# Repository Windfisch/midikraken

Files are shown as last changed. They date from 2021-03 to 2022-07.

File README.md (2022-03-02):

Midikraken
==========



binary_size (https://seriesci.com/Windfisch/midikraken/series/binary_size)

An open-source, open-hardware MIDI-USB-interface supporting up to 16
(and maybe beyond?) MIDI ports. The hardware is based on a STM32F103
*"blue pill"* board which can be cheaply sourced from your favourite chinese
seller ([note about quality differences](https://github.com/Windfisch/analog-synth/blob/master/bluepill.md)),
plus other garden variety components such as HC2630 opto couplers (that's just
two 6N137 in one package), shift registers, some LEDs and resistors.

Apart from being a MIDI-USB-interface, Midikraken is a feature-packed MIDI
router supporting separate clock and note event routing, clock division.
Future features may include split-keyboard routing, clock generation or even a
hardware arpeggiator.

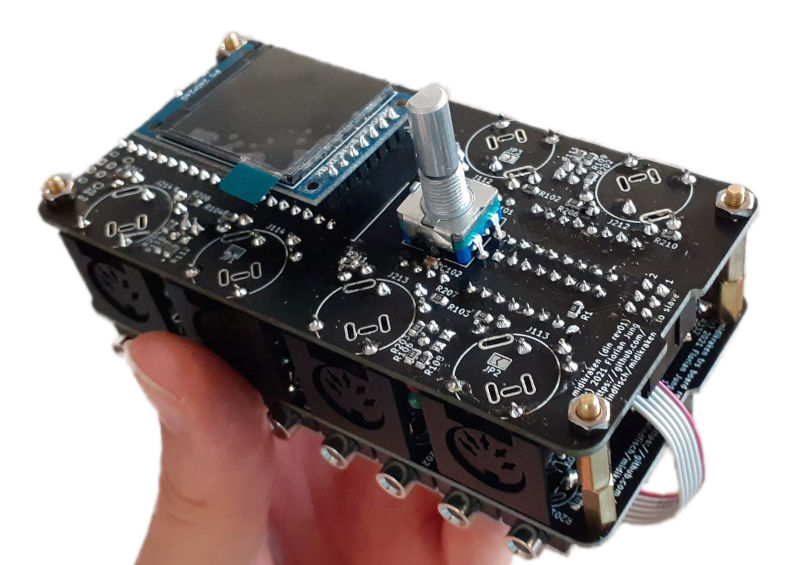
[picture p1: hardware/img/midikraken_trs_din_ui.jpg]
Example of a Midikraken configuration


Below you will find a technical overview. [A user manual is available here](documentation/README.md).

Releases
--------

Find the latest firmware upgrade packages [on the releases page](https://github.com/Windfisch/midikraken/releases).
You only need an USB cable, instructions for Linux and Windows are included.

The schematics and board layout files are [on a separate page](https://github.com/Windfisch/midikraken-hardware/releases).
Hardware and firmware are versioned separately, their numbers do not match.

Hardware
--------

Midikraken consists of two different PCBs that can be stacked (almost)
arbitrarily: [The DIN board](hardware/din5_pcb) has four traditional MIDI
in/out port pairs, and can house the master microcontroller.

[The TRS board](hardware/trs_pcb) gives you eight TRS MIDI pairs that support
both TRS-A and TRS-B. (Inputs are automatic, outputs need to be configured
in software). It can not house the microcontroller and thus cannot be used
without a DIN board.

The boards can be chained using their master/slave connectors and are
stackable using M3 screws / spacers. Currently, the firmware must be
adapted and recompiled according to the stack configuration. Currently,
a maximum of 16 port pairs is supported.

For information on the hardware, the revision history and errata, see [the hardware documentation](hardware/README.md).
A [build guide](documentation/build_guide/README.md) for rev01 and rev02 is available.

Firmware
--------

The firmware is written in Rust and is released under the GPLv3 license.

Since the STM32F103 only offers 3 hardware UARTs, we need to emulate the UART
protocol in software. For this, a timer interrupt oversamples the UART input pins
with thrice the baudrate in order to always read a stable bit at a non-edge.
(Guaranteed 1/3 * bit time distance from any edge, so the signal should be quite
stable until then.)

[Benchmarks show](firmware/benchmark/README.md) that this can be done fast
enough for up to 16 software UARTs (and likely even more), while leaving
plenty of cpu cycles (25% for 16 UARTs) free for other work.

Further information about the firmware itself can be found
[in the firmware documentation](firmware/README.md).

License
-------

The software in the [firmware](firmware) directory can be redistributed
and/or modified under the terms of the
[GNU General Public License Version 3](gpl3.txt). Note this does not apply
to the [bootloader](firmware/sboot/sboot_stm32) which is under its own
license.

The hardware designs in the [hardware](hardware) directory, excluding
[hardware/lib/3d](hardware/lib/3d) to which own conditions apply, can be
licensed under the terms of the [CERN OHL Version 2 license](cern_ohl_s_v2.txt).
This specifically includes (but is not limited to) schematics, PCB designs and
gerber files.

Contributing
------------

I am happy about contributions, just open a pull request!

**Note:** Even though Midikraken is licensed under GPLv3 and OHL-S-v2 (the exact
versions), any contributions / pull requests must be licensed under the
"GPLv3 *or any later version*" or "OHL-S-v2 *or any later version*", respectively.
This is because on the one hand, I want to be able to update the project to new
versions of these licenses, but on the other hand, I don't like licensing my work
under a license (e.g. the hypothetical GPLv4) that I haven't even read yet. If such
a license is released, I will likely adopt it after revising it.

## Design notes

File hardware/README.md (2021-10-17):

Midikraken hardware
===================

This page describes the hardware itself. A [build manual is available here](../documentation/build_guide/README.md).

Midikraken boards are meant to be **stacked** using M3 spacers and screws.
In such a setup, one "master" exists that holds the microcontroller with
the USB port, and zero or multiple "slaves" are daisy-chained with their
upstream ("from master") or downstream ("to slave") ports.

Photo of Midikraken

The photo shows an (almost) fully equipped Midikraken including:

- 1 DIN connector board (the large MIDI connectors).
- 1 TRS connector board (MIDI via headphone jacks).
- The main microcontroller
- The UI consisting of a display and a rotary encoder.

Midikraken boards can be stacked almost arbitrarily; the only limit is
(currently) a maximum of 16 MIDI in/out port pairs.

Two board types are available:
- The DIN board with four DIN MIDI inputs and four outputs
- and the TRS board with eight TRS inputs and eight outputs.

DIN boards may or may not house the main microcontroller, so every stack needs
one. Note that the DIN board can be used to house only the microcontroller, if
desired. No actual MIDI ports need to be equipped, making a TRS-only stack
possible.

The TRS board supports both TRS-MIDI-A and -B (where roles of tip and ring
are swapped).

Note that while it would be possible to design boards with
only inputs or only outputs, the current boards do *not* support switching
an input port to output mode or vice versa. If desired, however, inputs
can be left unmounted; in this case, the appropriate LEDs and opto-couplers
can be left out, too.

Board variants
--------------

Both boards can be built in different variants. For the DIN board, the options
include:

- It can either house the **microcontroller** *(A1)* or act as a **slave** *(A2).
- It can hold **angled MIDI connectors** (*B1*, the default), or **not have any connectors** *(B2)*.
  (This is useful when used as user interface board only). *(Additionally, there
  is a somewhat hacky way to mount upward-facing MIDI connectors to it for use
  in Eurorack setups, but that's dirty and untested.)*
- If the board is configured as a master, it can or can not have a **user
  interface** *(C)* consisting of a display and a rotary knob with a push button.
- If the board holds a microcontroller, it can support chaining more boards to it *(D1)*,
  or save some components at the cost of losing the chaining ability *(D2)*. (*not
  recommended*).
- In this case, MIDI can be driven with 5V *(E1)* or with 3.3V *(E2, saves another chip, 
  not recommended)*.
- As a the buffer U1, a 74HCT245 *(F1)* or 74HCT541 *(F2)* can be used.

For the TRS board, two options are available:
- Either 8 in/out port pairs are mounted *(X1)*
- or only one side is equipped with only 4 in/out pairs *(X2)*
- **Angled TRS jacks** (PJ-324) *(Y1)* or **upright** TRS jacks *(Y2)* can be used.

The following components need or need not be mounted on the PCB:
- *(A1)*: mount A1, J1, U1; leave J3 unmounted.
- *(A2)*: mount J3, leave A1, J1, U1 unmounted.
- *(B1)*: mount J10x and J20x, U101, U102, U2, U3 and Dxxx.
- *(B2)*: do not mount the components from *(B1)*, instead run a copper wire across *TODO*.
- *(C)*: mount or do not mount J8 and SW1.
- *(D2)*: Close JP1-4, and close JP5-8 according to your selection in *(E)*.
- *(E2)*: Do not equip U1.
- *(F)*: Configure JP9 accordingly.
- *(X2)*: Close JP102 and do not mount Jx05-Jx08, and all LEDs and resistors on this side.
 Also do not mount U205-U208.
- *(Y)*: Solder in what is needed, the PCB can hold both.

**Note:** While this sounds complicated, in the recommended default configuration which is reflected
by the BOM and schematics, only JP9 needs to be closed to select the IC type used in U1. All other
solder bridges are left open and no deviations from the schematic need to be made, except for *(A)*.

Currently, two different hardware revisions exist. They are described here from most recent to
oldest.

Revision 01
-----------

### Bill of material

[din5_pcb/bom.html](https://htmlpreview.github.io/?https://github.com/Windfisch/midikraken/blob/master/hardware/din5_pcb/bom.html),
[interactive BOM](https://htmlpreview.github.io/?https://github.com/Windfisch/midikraken/blob/master/hardware/din5_pcb/ibom.html)

[trs_pcb/bom.html](https://htmlpreview.github.io/?https://github.com/Windfisch/midikraken/blob/master/hardware/trs_pcb/bom.html),
[interactive BOM](https://htmlpreview.github.io/?https://github.com/Windfisch/midikraken/blob/master/hardware/trs_pcb/ibom.html)

### Errata

During powerup, the MIDI ports send garbage bits. To fix this,
you need to disconnect the 74HC595s' *output enable* pins from GND
using a sharp knife (and some wire to reconnect all GNDs that should stay
connected), and connecting them like this instead:

```
+5V --- Capacitor 10µF --- OE pin --- Resistor 10k --- GND
```

This delays the output enable enough such that the shift registers can
be filled with proper data after the microcontroller has booted up.

The exact fixing procedure is described in [this document](../documentation/rev01_fix/README.md).

### Eurorack compatibility

Please note that Midikraken was designed as a standalone adapter box. However,
where possible, efforts were made to make Midikraken as Eurorack compatible as
possible:

- The PCBs are 110mm in height, fitting tightly into any Eurorack setup.
- The boards are prepared for upright connectors. This is sort of hacky, but it
  might work. The TRS board can hold PJ392 sockets that are usually meant to
  have wires soldered to their legs. The DIN board can hold DIN sockets similar
  to the NYS325, with a hack: The outermost two solder tail must be removed, and
  the remaining three must be bent so that they fit into the PCB.
- Alternatively, any socket can be used and wires can be soldered to the PCB.

Enclosure
---------

Midikraken can either be built half-open as shown in the photo above, or can be
protected from dust and metallic parts with a 3d-printed enclosure.  The
enclosures reflect Midikraken's modular nature and itself can be stacked onto
each other. Currently, three enclosure modules exist:

- The [**display shell**](cad/display_shell.FCStd) which is put on top of the DIN5
  PCB and holds the display.  It terminates the Midikraken stack to the upper
  side.
- The [**DIN5 shell**](cad/din5_shell.FCStd) which is put on the opposite side of
  the DIN5 PCB and covers the MIDI ports, leaving cutouts for the LEDs and the
  USB port.
- The [**TRS shell**](cad/trs_back_shell.FCStd) which covers the ports of the TRS
  PCB and terminates the Midikraken stack.
- Additionally, the [**display top plate**](frontplate) and [**back plate**](backplate)
  are alternatives to the display shell and should be used in the half-open,
  caseless configuration to support the display and protect the circuitry.

The enclosure light guides that cover the LED holes and make it easier to see
the LEDs from an angle. These guides are to be printed with transparent material
and are snapped in from the inside.
(DIN5 needs 4 of [these](cad/din5_lightguide.FCStd) and TRS needs 8 of [these](cad/trs_lightguide.FCStd))

Yet to be done:

- A **terminating DIN5 shell** with a bottom plate for builds without a TRS shell.
- A **non-terminating TRS shell** for builds that use more than one TRS board.
  Note that currently, the firmware only supports a maximum of 16 MIDI ports, which
  rules out a two-TRS-board-solution for now.

Ghettokraken on perfboard
-------------------------

Schematics for the first prototype board were created with KiCAD and are
located in [perfboard](perfboard).

A 3D-printed enclosure (which needs some adjustments to fit well) was
designed in FreeCAD and resides in [perfboard/cad/](perfboard/cad/).
The enclose provides the DIN ports with additional stability which the
usual perfboards lack.

**Note**: You need to use the firmware from 7072a0c6eb or earlier due
different pin assignment; or you reassign the pins.

This roughly resembles the *(D2, E2)* configuration

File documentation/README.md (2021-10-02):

Midikraken user manual
======================

This user manual is targeted to the tech-savvy end user who wants to assemble
Midikraken and get started as quick as possible. Technical details are not discussed here.

If you have received a Midikraken DIY kit, follow [the build guide](build_guide/README.md)
and assemble the Midikraken.

To update the firmware, see [the firmware upgrade manual](firmware_upgrade/README.md).

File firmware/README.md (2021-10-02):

Firmware
--------

The firmware is written in Rust. It can be used either bare metal or with a
bootloader.

### Flashing without a bootloader

  - Connect RX/TX of your uart/usb-adapter to PA9/PA8.
  - Put the STM32 into download mode by setting BOOT0 high and resetting.
  - `cd firmware`
  - `make flash.bare.release` (assuming that `ttyUSB0` is your uart adapter)

### Flashing and using a bootloader

#### Preparing the bootloader

Building with the `--features=bootloader` flag enabled will relocate the
program entry point to `FLASH + 0x2000`, allowing to use a bootloader.

Follow [these steps](sboot/README.md) in order to build and
initially flash the bootloader. You only need to perform this once.

#### Flashing the firmware

Bootloader mode can be entered by sending the `sboot/bootloader.syx` sysex to
the zeroth output of the midikraken (e.g. using `amidi -p hw:1,0,0 -s bootloader.syx`).

If that does not work (e.g. because the firmware is not present or corrupt), pull
PB12 low and reset.

  - Connect the Midikraken to USB
  - (in case of a defective firmware, pull PB12 low and reset)
  - `cd firmware`
  - `make flash.dfu.release` (will send the reset sysex automatically)

### Debugging

printf-debugging can be seen on PA9/PA10 with 38400 baud. In the default
configuration, you should see only

```
========================================================
midikraken @ 6b3d42c5bf369a8da5d348a39342b91c2a3f7e80
      built on 2021-04-09T18:50:50.306707469+00:00
========================================================
```

You can enable more debug information with the `debugprint` flag.

Note that this degrades performance close to being unusable.

### Benchmarking

The software UART timer interrupt fires 93750x per second. This leaves
only 768 cpu cycles per call to the ISR.

To measure the performance of the software UART in the worst-case scenario
(all receivers are receiving their last bit and thus are finishing, and all
senders fetch their next byte and start transmitting it), enable the
`benchmark feature flag`. Note that this will send and receive garbage data.

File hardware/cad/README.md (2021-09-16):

# Enclosures

Midikraken can optionally be put in an enclosure to protect it from dust and metallic parts that
could get inside.  Alternatively, it can be left half-open.

## Modular closed solution

For the closed solution, 3D-print the `display_shell`, `trs_back_shell` and `din5_shell`. You need
4x 22mm M3 spacers, 4x M3 screws and 4x M3 nuts to put everything together.

Place the nuts in the appropriate holes in `trs_back_shell`, then place the TRS board on top and
screw in the spacers.  Put the DIN5 shell onto the DIN5 board, connect the data cable and place the
DIN5 board on top of the TRS board. Now, mount the display on the display shell and carefully place
it onto the DIN5 board. Ensure that the display connector actually meets the receptacle. Then put in
the screws so everything holds together.

## Half-open solution

You will need one extra TRS or DIN5 board which has no parts soldered on. Also, you will need either
a 3D-printed `display_plate`, or the same thing fabricated from PCB material (preferred).
Additionally, 4x 22mm and 8x 16mm spacers are needed.

Basically, you create a sandwich from the empty PCB (used as bottom plate), then the TRS board, the
DIN5 board, and the display plate (with the display already mounted). These are connected by the
spacers.

It is recommended to use brass spacers here, for looks and for mechanical stability.

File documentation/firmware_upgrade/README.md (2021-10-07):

Upgrading the firmware
======================

If a new firmware is released, you can easily upgrade your Midikraken to the most recent version
via USB. First, download the firmware image from [here](https://github.com/Windfisch/midikraken/releases),
then follow the steps below depending on
your operating system. **Do not unplug the device during the flash procedure or you might damage
the firmware.**

If, however, your Midikraken failed to upgrade and now is in an inoperable state and does not show up
as USB device, read the rescuing section below.

## A note about beta software

The midikraken firmware is currently in its early beta phase, so there could be bugs. If you find one,
please check [the issue tracker](https://github.com/Windfisch/midikraken/issues) whether it was already
reported. If not, please report it through the issue tracker or via mail.

Please note that firmware upgrades can occasionally lose your settings due to changes in the save format.
One or two such breakages *will* happen with one of the next firmware upgrades. Such breakage will be
announced in the release notes.

Port numbering is currently non intuitive and is subject to change in one of the next releases.

## Linux

Only if you are flashing the firmware for the first time, give your user permission to flash the device
by executing the following as root user:

```
gpasswd plugdev -a YOUR_USERNAME_HERE    # note: if the plugdev group does not exist, replace it by "uucp" in all steps
echo 'SUBSYSTEMS=="usb", ATTRS{idVendor}=="1209", ATTRS{idProduct}=="2e7f", GROUP="plugdev", MODE="0666"' >> /etc/udev/rules.d/50-dfu.rules
udevadm control --reload
```

To actually flash the firmware, as your normal user account, extract the firmware zip, open a
terminal, navigate to the extracted files and execute the `flash.sh` script.

## Windows

Unpack the firmware package.

If you are flashing the firmware for the first time, you need to install the WinUSB driver first.
To do so, execute the `install_driver.bat` script from the firmware package with the device attached.
This will reset Midikraken into bootloader mode, and then open Zadig. Open the *Options* menu and check
*"List All Devices"*. Then, from the combo box, select *"Midikraken bootloader"*. Next to the green arrow,
select *"WinUSB"*. Then click *"Install driver"* and close Zadig.

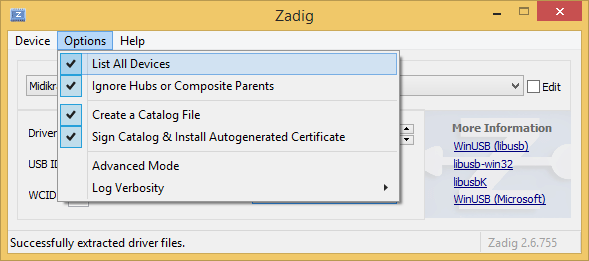
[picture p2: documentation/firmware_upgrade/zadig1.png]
Select List All Devices

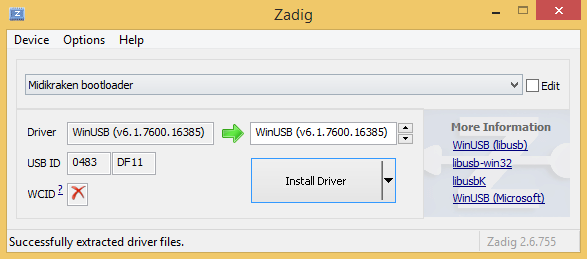
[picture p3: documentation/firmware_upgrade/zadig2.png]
Install Driver


Now you are ready to flash the firmware by executing `flash.bat`.

## Mac OS

TODO. Probably you want to use [brew](https://brew.sh/) to install `dfu-util`, send the `bootloader.syx`
SysEx to output 1 of your midikraken somehow, and then upgrade the firmware as described in the Linux
section using dfu-util.

Rescuing the firmware
=====================

If the device does not show up via USB and the display does not work any more, likely the firmware
was damaged.

Midikraken contains a bootloader, i.e. a small program that allows the device to self-update via USB.
This bootloader is usually called from the firmware, but if the firmware is damaged, it is possible
to force Midikraken into the bootloader mode.

To do so, unscrew the top shell and carefully detach the DIN5+display assembly from the TRS board.
Be sure to not rip out the cable. You now are able to view the top side of the STM32 blue pill board.
Locate the pins labelled "B12" and "G" that are left and right of the USB port. Unplug the USB cable,
then use a pair of tweezers to connect the "B12" pin with "G". Plug in the USB cable while shorting
these two pins. Now a "Midikraken bootloader" device should show up. Proceed to flash the firmware
as usual.

In the highly unlikely event that you have a defective bootloader, you will need additional hardware
to re-flash the bootloader. This can be done either using a UART adapter or using a JTAG/SWD debugger,
e.g. a STLINK or a Blackmagic probe. Follow
[these instructions](https://github.com/Windfisch/midikraken/blob/master/firmware/sboot/README.md) to
build and flash the bootloader.

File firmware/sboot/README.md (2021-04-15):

# Building the bootloader

Ensure that you have checked out the `sboot_stm32` submodule. If you
have not `git clone`d with the `--recursive` option, execute
`git submodule update --init` now.

  - `git submodule update --init`
  - `cd sboot_stm32`
  - `make prerequisites`
  - `make DFU_USER_CONFIG=../userconfig.h stm32f103x8`
  - flash `build/firmware.bin` to your device using one of the following ways:
    - using a ST-LINK
    - or set the *BOOT0* jumper to *high*, reset the board, connect a USB-UART
      adapter as follows: RX -> PA9, TX -> PA10, GND -> GND. Then use e.g.
      [stm32flash](https://sourceforge.net/projects/stm32flash/).

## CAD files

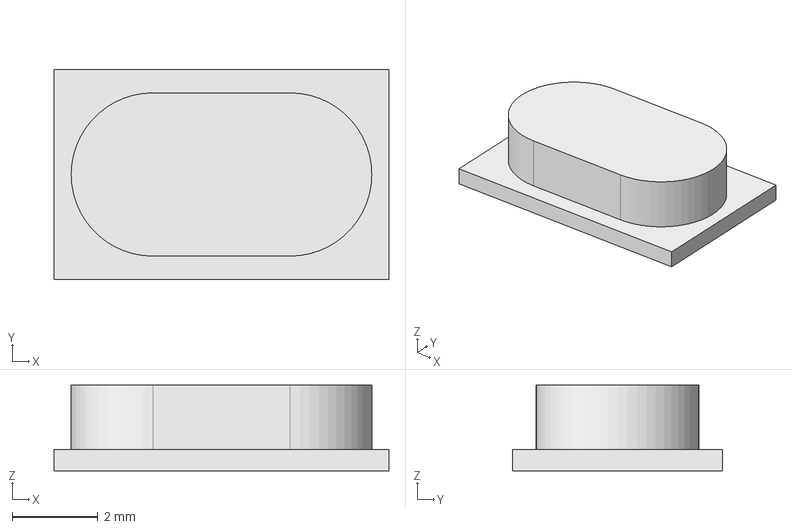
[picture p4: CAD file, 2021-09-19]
hardware/cad/din5_lightguide.FCStd
7.80 x 4.90 x 2.00 mm

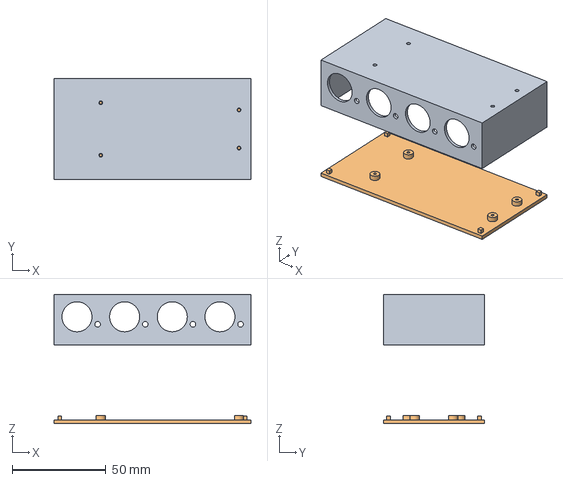
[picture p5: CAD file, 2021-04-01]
hardware/perfboard/cad/perfboard.FCStd
105.0 x 54.0 x 69.0 mm

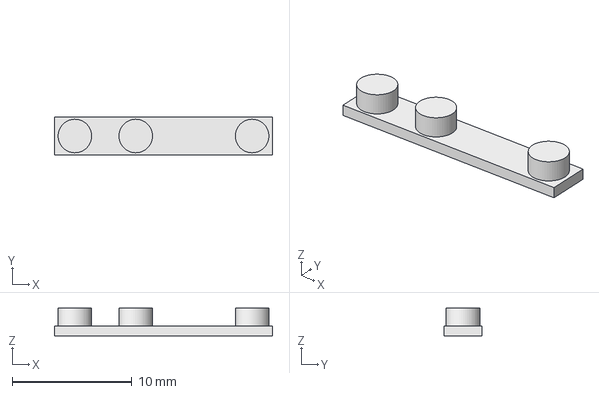
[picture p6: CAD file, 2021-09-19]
hardware/cad/trs_lightguide.FCStd
18.2 x 3.20 x 2.30 mm

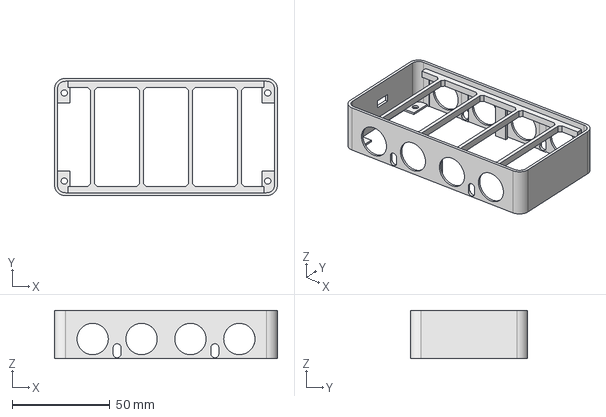
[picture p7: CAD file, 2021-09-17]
hardware/cad/din5_shell.FCStd
114.0 x 60.0 x 24.6 mm

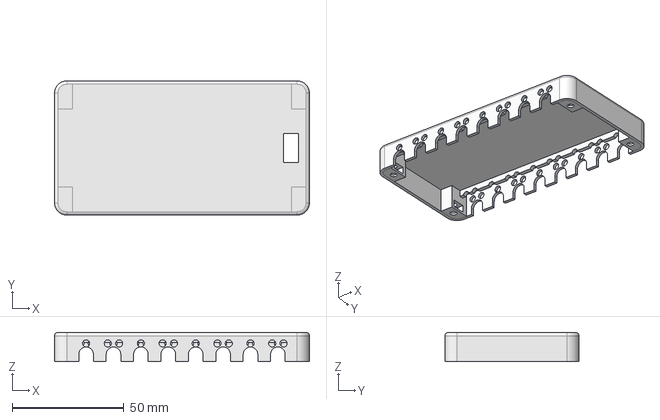
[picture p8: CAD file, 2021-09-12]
hardware/cad/trs_back_shell.FCStd
114.0 x 60.0 x 13.0 mm

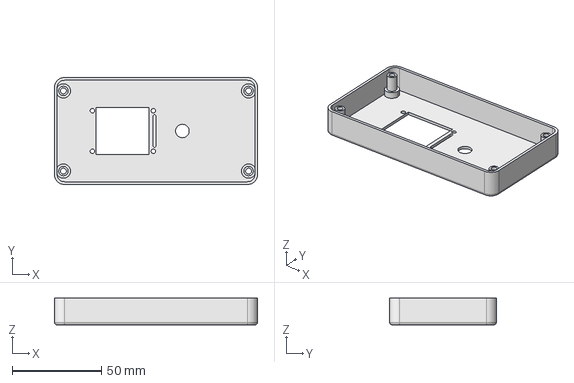
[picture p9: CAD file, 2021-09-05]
hardware/cad/display_shell.FCStd
114.0 x 60.0 x 15.1 mm

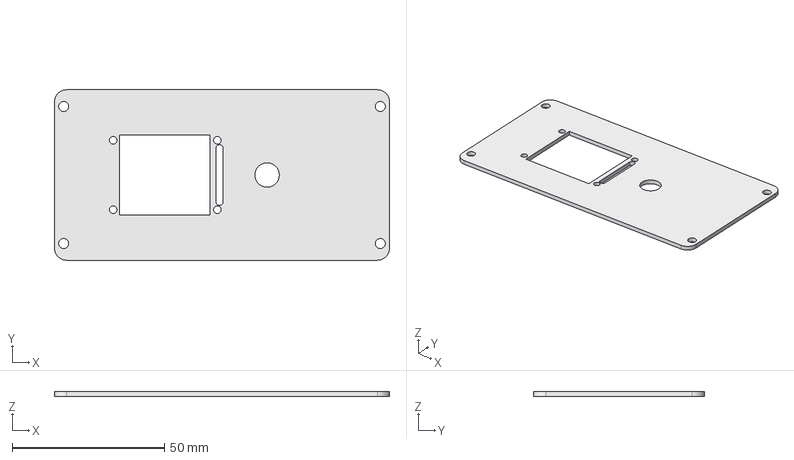
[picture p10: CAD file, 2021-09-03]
hardware/cad/display_plate.FCStd
110.0 x 56.0 x 1.60 mm

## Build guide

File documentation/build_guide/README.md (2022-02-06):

Midikraken build howto
======================

Since Midikraken is designed to be modular and is quite configurable, countless configuration
options exist. Not all of them can be described here, and not all of them have been actually tried.

The following guide will focus on the following configuration:
- One DIN5-board with a display and the microcontroller.
  (In [A1 B1 C+ D1 E1 configuration](../../hardware/README.md#board-variants))
- One TRS-board. (In [X1 Y1 configuration](../../hardware/README.md#board-variants))

Photo of Midikraken

This guide will leave up to you whether you want an enclosure or whether you prefer the half-open
configuration.

Step 1: Obtaining all parts
---------------------------

Check that you have obtained all parts from
[the din5 BOM](https://htmlpreview.github.io/?https://github.com/Windfisch/midikraken/blob/master/hardware/din5_pcb/ibom.html)
and [the TRS BOM](https://htmlpreview.github.io/?https://github.com/Windfisch/midikraken/blob/master/hardware/trs_pcb/ibom.html)
(except those in parentheses or those that say "as desired", we'll handle them separately).

Additionally, you require the following parts:

- 1x DIN5 PCB
- 1x TRS PCB
- 2 box connector terminators
- 5cm (or more) of 6x 1.27mm pitch wire for the box connectors.
- **if you want an enclosure**:
  - 3D prints of the three enclosure parts ([din5_shell](../../hardware/cad/din5_shell.FCStd),
    [trs_back_shell](../../hardware/cad/trs_back_shell.FCStd), [display_shell](../../hardware/cad/display_shell.FCStd)). Print
    them in any color your like, black PLA with 0.2mm layer height and 10% cubic infill worked fine
    for me. Rotate the DIN5 shell such that the enforcements are close to the bottom side; use
    paint-on-supports for the mounting latches and for the crossings of the enforcement beams. Use
    no support for the other shells.
  - 3D prints of the light guides: 4x [din5](../../hardware/cad/din5_lightguide.FCStd) and 8x
    [trs](../../hardware/cad/trs_lightguide.FCStd). These *must* be printed in transparent and with 100% infill.
    Overture transparent PETG at 0.1mm layer height worked fine for me.
  - 4x 16mm M3 hex screws
- **else if you prefer the half-open solution**:
  - 3D print of the [front plate](../../hardware/frontplate) (or fabricated PCB or any other means of
    manufacturing a plate).
  - One additional DIN5 *or* TRS PCB which is used as bottom plate, or [the bottom plate](../../hardware/backplate)
  - Optional: a 3d printed trs_back_shell is useful for aligning the LEDs during build.
  - 4x 6mm M3 screws
  - 4x 16mm brass spacers
  - 4x 12mm brass spacers
- 4x 22mm brass spacers
- 4x M3 nuts
- 4x 6mm M2 screws
- 4x M2 nuts

Step 2: Soldering the PCBs
--------------------------

First, read the [instructions on how to fix rev01 boards](../rev01_fix/README.md).
Before soldering anything make the cuts described there.

It is expected that you know how to solder DIP and easy SMD components. A quick reminder:

- Use a soldering iron with a flat tip. Pointy tips are bad at transferring heat.
- Heat both the pin and the pad on the PCB well to ensure a good connection.
- Solder "from small to large" parts.

First, put together the blue pill board. You can use a second PCB to ensure that the pins are
soldered on straight.

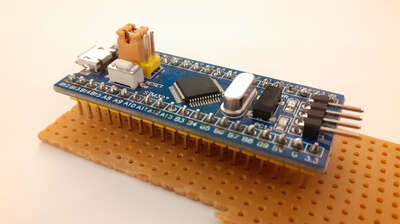
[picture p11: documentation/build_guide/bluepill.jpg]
Blue Pill Board


The procedure for the DIN5 and TRS boards is mostly similar. In order to find out the correct part
values, please refer to
[the din5 BOM](https://htmlpreview.github.io/?https://github.com/Windfisch/midikraken/blob/master/hardware/din5_pcb/ibom.html)
and [the TRS BOM](https://htmlpreview.github.io/?https://github.com/Windfisch/midikraken/blob/master/hardware/trs_pcb/ibom.html).

0. If you have a rev01 board, ensure you cut the right traces on the PCB.
1. DIN5 board only: Close the JP9 solder bridge by putting a blob of solder across the middle and upper
   pad (assuming that you use a 74HCT245 chip).
2. DIN5 board only: Close the JP14 solder bridge to select 5V.
3. Solder all resistors and capacitors. (*A good procedure for this is to put some solder on
   *one* of the two pads, then grab the resistor with the tweezers and push it onto the solder blob
   while still heating the solder blob with your iron. Afterwards, put solder on the other side of
   the part as well. [Random video tutorial](https://www.youtube.com/watch?v=lrDyUj7ZfVI)*)
4. Proceed with all ICs. Ensure their correct orientation indicated by a latch on one side, or a
   small dot.
5. If you have a rev01 board, finish the fix by adding the resistors first (similar to the above
   procedure), and then attach the coated wire. Heating your soldering iron to 420C will easily burn
   away the wire coating and ensure good connection. You can now just heat a solder blob and stick
   the wire end into it.
6. Solder the box connectors ("to slave" on the DIN5 board, "from master" on the TRS board), and J3
   on the DIN5 board only. Ensure the correct orientation as denoted on the board.
7. DIN5 board only: Place the 1x20 pin headers on your blue pill board, then insert the header onto
   the PCB and solder it in. Then remove the blue pill board from the headers again.
8. Mount the TRS connectors.
9. Add the LEDs to the TRS board. Stick them
   through the holes so that the short lead is barly sticking out on the soldering side, then bend
   the LEDs over the TRS connectors. Do not rotate the board or they will fall out. When you have
   placed all LEDs, put the TRS case on and ensure all LEDs are held into the right position. Rotate
   the case-board-sandwich and solder the LEDs. Then remove the case again.
   The **long lead** (anode) goes into the **round hole**, and the short lead into the square hole.
10. Solder in the LEDs on the DIN5 board. First, put in the red led and fold it by 90 degrees; then
    put the green led behind and fold it such that it is above the red led.
    Again, the **long lead** (anode) goes into the **round hole**, and the short lead into the square hole.
11. Mount the DIN5 connectors.
12. DIN board only: on the opposite side, solder in the J8 header and the SW1 encoder. You will need
    to trim the two side legs a bit, or they would collide with the ICs on the other side. Soldering
    in the side legs is a bit tricky and must be done "from the wrong side". On the other hand,
    these side legs are optional and only provide stability. Be sure to solder in the rotary knob
    straight, mistakes are impossible to fix.

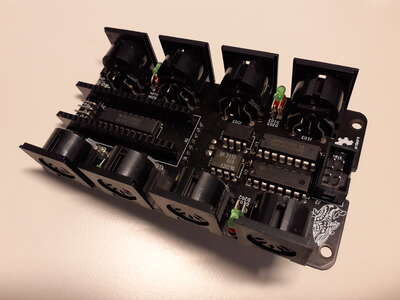
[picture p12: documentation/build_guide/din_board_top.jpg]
DIN board

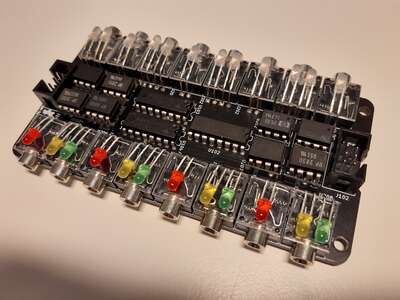
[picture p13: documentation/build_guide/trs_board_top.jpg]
TRS board


Finally, insert the 6-wire 1.27mm pitch lead into the box connector terminators as shown on the
photo. Don't waste wire length. Then push the terminators together with force so they cut
into the wire and form a connection.

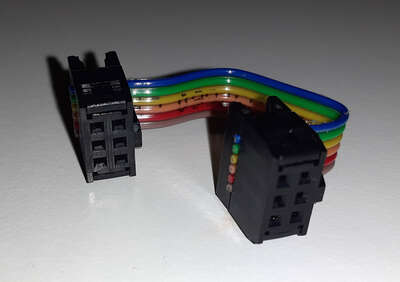
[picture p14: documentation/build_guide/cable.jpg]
Box connectors on cable


Step 3: Testing basic functionality
-----------------------------------

Attach the bare blue pill board via USB to your computer. The power LED should light up and you
should see a Midikraken USB device. Disconnect USB.

Now place the blue pill board on the DIN5 board. Do not attach the display yet. Connect it to USB
again, you should see a Midikraken USB device again. Send some notes to one of the first four ports.
You should see the corresponding LED flashing. Connect a Midikraken's output to one of its inputs.
You should see the input LED flashing, too, when transmitting data. Use MIDI software to check that
you actually receive MIDI data on the input.

Disconnect USB, add the display into the header and re-connect USB. You should see the main menu.
Rotate the button and click to select a menu entry.

Disconnect USB, and connect the TRS board to the DIN5 board using the TRS board's "from master"
connector. Re-attach USB and send MIDI to one of the last eight ports. The TRS board's LEDs should
flash. Connect one of its outputs to one of its inputs, similarly, the input led should flash too
and your MIDI application should register data being received.

Remove all wires.

Step 4: Flashing the latest firmware
------------------------------------

Download the latest firmware from [here](https://github.com/Windfisch/midikraken/releases/tag/firmware_v0.1.1),
connect the device via USB and flash it using [these instructions](../firmware_upgrade/README.md).

Disconnect and reconnect USB to check whether the device still shows up as "Midikraken" USB device.
If it doesn't follow the recovery instructions under the link above.

Remove all wires.

Step 5a: If you have an enclosure: Enclosure assembly
-----------------------------------------------------

### Shell preparation

First, break of the supports from the DIN enclosure. Then trim away all 3d print artifacts using
a sharp blade:

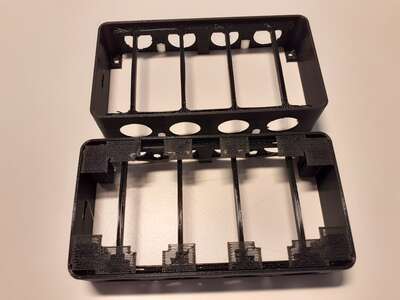
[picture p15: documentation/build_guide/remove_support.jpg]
Breaking the supports

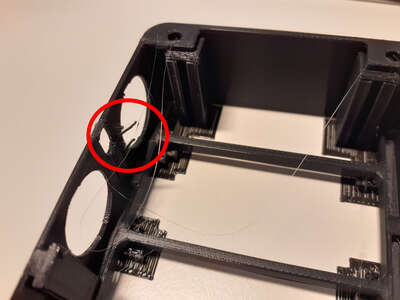
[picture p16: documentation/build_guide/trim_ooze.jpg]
Trimming artifacts


Then snap in the transparent light guides into the TRS and DIN shells. Grab the TRS light guides
with a pair of tweezers, put the TRS case on its side and lay the light guides in place. Then
firmly press them into their holes, starting from the middle. Be sure to not break the walls off.

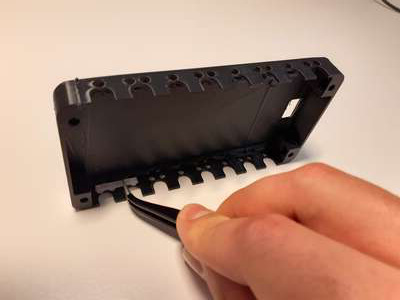
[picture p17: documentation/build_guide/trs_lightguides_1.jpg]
Inserting the light guides

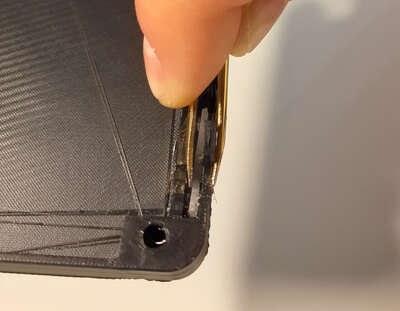
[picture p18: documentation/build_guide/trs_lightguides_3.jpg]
Snapping in the light guides


Use tweezers to remove the 3d print spaghetti from the screw slots in the TRS board. Grab a string
and twist it around until it comes off.

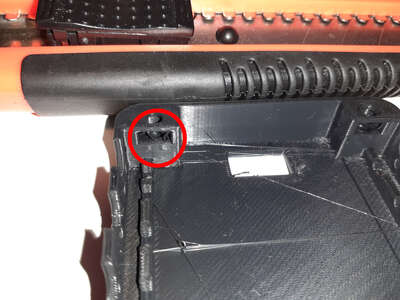
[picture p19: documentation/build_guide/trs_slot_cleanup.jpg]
screw slots

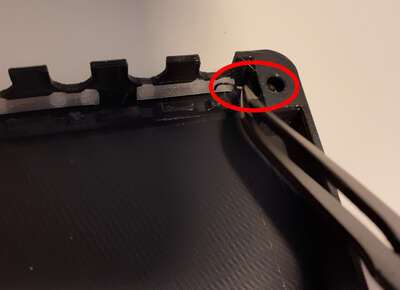
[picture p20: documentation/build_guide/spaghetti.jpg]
Removing the spaghetti


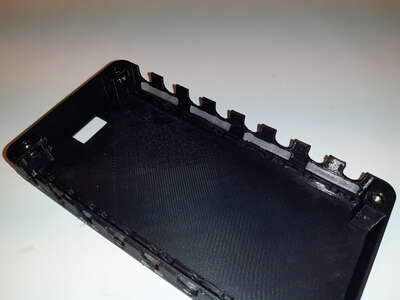
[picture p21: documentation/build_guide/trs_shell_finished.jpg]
Finished TRS shell

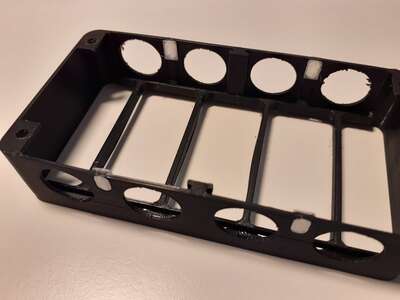
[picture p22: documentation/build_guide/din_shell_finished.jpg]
Finished DIN shell


Mount the display into the display shell from below using the M2 screws and nuts.
Ensure you can slide the four M3 screws through the holes in the display shell. It might be
neccessary to insert them from the opposite side first and to clear any excess plastic / print
artifacts.

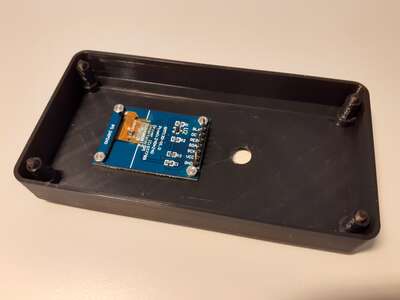
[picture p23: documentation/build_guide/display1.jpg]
Display shell back side

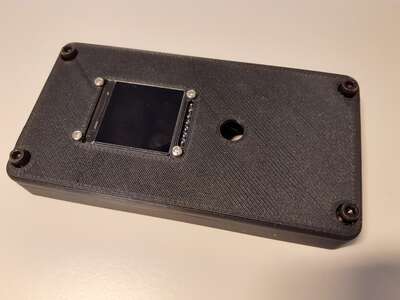
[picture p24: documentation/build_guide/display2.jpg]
Display shell front side


### Adding the boards

Slide the DIN5 case over the DIN5 connectors. Be sure to not cover the USB connector and that
the nose in the middle latches into the middle two DIN5 connectors for improved stability.

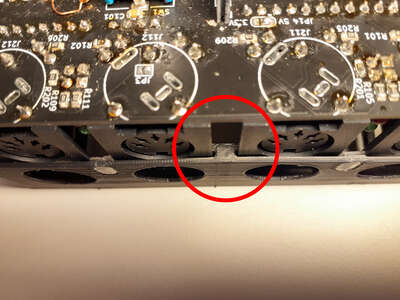
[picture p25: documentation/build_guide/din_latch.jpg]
Latching in the DIN shell


Plug in the master/slave cable into the TRS board's *"from master"* header and place the four M3 nuts into the slots in the
enclosure. Make sure they don't fall out. Put the TRS board on top. Once the board is in place, the
nuts are held in place and cannot fall out any more. Screw in the 22mm M3 brass spacers to lock
everything in place. Be sure that the master/slave cable comes out at the small slot in the PCB.

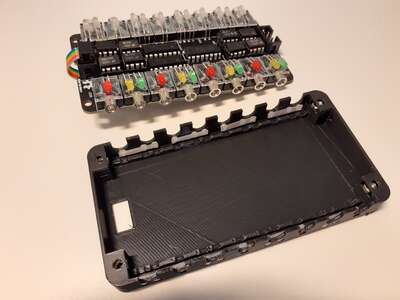
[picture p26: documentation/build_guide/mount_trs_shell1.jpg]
Cable inserted into the TRS board

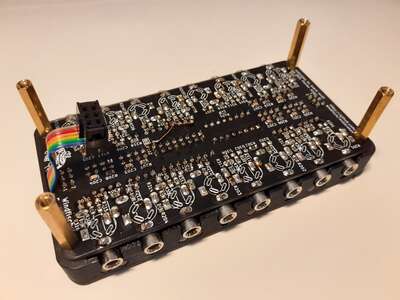
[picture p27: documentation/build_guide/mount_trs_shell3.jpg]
Finished TRS assembly


*Note: the photos show the wrong orientation. The cable must be inserted into "from master", not into
"to slave" as shown on the photos.*

Now plug in the cable into the "to slave" connector of the DIN5 board. Then place the TRS board on
top / below of the DIN5 board. Screw in the four M3 screws through the display shell and the DIN5
board into the brass spacers.

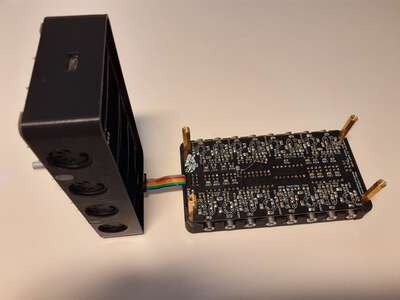
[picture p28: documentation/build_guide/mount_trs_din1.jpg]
Inserting the cable into the DIN board

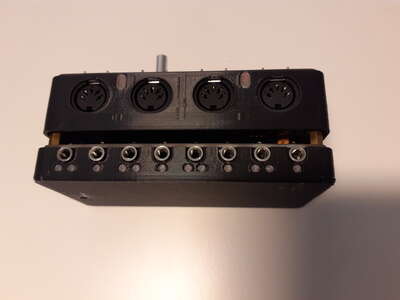
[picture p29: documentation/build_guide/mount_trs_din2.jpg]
TRS and DIN boards put together


**Carefully** place the display shell on top of the DIN5 board. Ensure that the display pins have
actually met the display socket. Put the button knob on the button to provisorily lock the shell in
place. Attach USB and check whether the display still works. Disconnect USB again.

Congratulations, your Midikraken is complete. :)

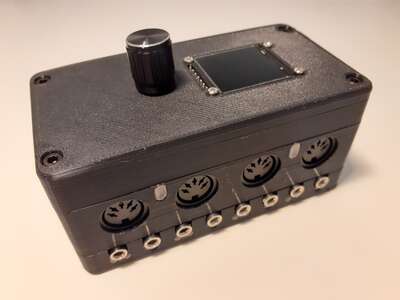
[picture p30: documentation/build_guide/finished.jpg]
Finished Midikraken

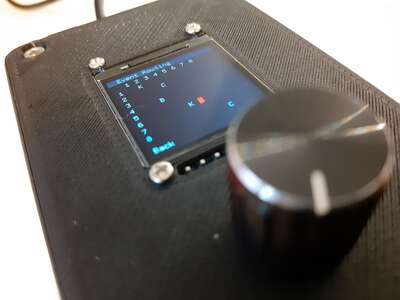
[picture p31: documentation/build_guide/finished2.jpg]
Finished Midikraken


Step 5b: If you prefer the half-open solution: Assembly
-------------------------------------------------------

Screw the 4x TODO mm spacers into the spare PCB / bottom plate and secure them with the M3 nuts.

Mount the TRS board on top and add the 22mm spacers.

Connect the TRS board and the DIN5 board using the master/slave connections, put the DIN5 board on
top of the TRS board and screw in the 12mm spacers.

Mount the display into the display plate using the M2 screws and nuts.

**Carefully** place the display place on top of the 12mm spacers. Ensure that the display pins have
actually met the display socket. Screw everything together using the M3 screws.

Congratulations, your Midikraken is complete. :)

Troubleshooting
---------------

**All output leds on the TRS board are lit.** Is the cable should be plugged into the TRS board's "from
master" socket, as it should be?

**No display output.** Have the display pins actually met the display header on the board? Inserting them
right can be a bit tricky.

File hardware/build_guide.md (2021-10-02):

Midikraken build howto
======================

Since Midikraken is designed to be modular and is quite configurable, countless configuration
options exist. Not all of them can be described here, and not all of them have been actually tried.

The following guide will focus on the following configuration:
- One DIN5-board with a display and the microcontroller.
  (In [A1 B1 C+ D1 E1 configuration](README.md#board-variants))
- One TRS-board. (In [X1 Y1 configuration](README.md#board-variants))

Photo of Midikraken

This guide will leave up to you whether you want an enclosure or whether you prefer the half-open
configuration.

Step 1: Obtaining all parts
---------------------------

Check that you have obtained all parts from
[the din5 BOM](https://htmlpreview.github.io/?https://github.com/Windfisch/midikraken/blob/master/hardware/din5_pcb/bom.html)
and [the TRS BOM](https://htmlpreview.github.io/?https://github.com/Windfisch/midikraken/blob/master/hardware/trs_pcb/bom.html)
(except those in parentheses or those that say "as desired", we'll handle them separately).

Additionally, you require the following parts:

- 1x DIN5 PCB
- 1x TRS PCB
- 2 box connector terminators
- 5cm (or more) of 6x 1.27mm pitch wire for the box connectors.
- **if you want an enclosure**:
  - 3D prints of the three enclosure parts ([din5_shell](cad/din5_shell.FCStd),
    [trs_back_shell](cad/trs_back_shell.FCStd), [display_shell](cad/display_shell.FCStd)). Print
    them in any color your like, black PLA with 0.2mm layer height and 10% cubic infill worked fine
    for me. Rotate the DIN5 shell such that the enforcements are close to the bottom side; use
    paint-on-supports for the mounting latches and for the crossings of the enforcement beams. Use
    no support for the other shells.
  - 3D prints of the light guides: 4x [din5](cad/din5_lightguide.FCStd) and 8x
    [trs](cad/trs_lightguide.FCStd). These *must* be printed in transparent and with 100% infill.
    Overture transparent PETG at 0.1mm layer height worked fine for me.
  - 4x 16mm M3 hex screws
- **else if you prefer the half-open solution**:
  - 3D print of the [display plate](display_plate.FCStd) (or fabricated PCB or any other means of
    manufacturing a plate).
  - One additional DIN5 *or* TRS PCB which is used as bottom plate.
  - Optional: a 3d printed trs_back_shell is useful for aligning the LEDs during build.
  - 4x 6mm M3 screws
  - 4x 16mm brass spacers
  - 4x TODO mm brass spacers
- 4x 22mm brass spacers
- 4x M3 nuts
- 4x 6mm M2 screws
- 4x M2 nuts

Step 2: Soldering the PCBs
--------------------------

First, read [Fixing the DIN5
board](https://github.com/Windfisch/midikraken/blob/master/hardware/README.md#fixing-the-din-board)
and [Fixing the TRS
board](https://github.com/Windfisch/midikraken/blob/master/hardware/README.md#fixing-the-trs-board).

Before soldering anything make the cuts described in these links.

It is expected that you know how to solder DIP and easy SMD components. A quick reminder:

- Use a soldering iron with a flat tip. Pointy tips are bad at transferring heat.
- Heat both the pin and the pad on the PCB well to ensure a good connection.
- Solder "from small to large" parts.

First, put together the blue pill board. You can use a second PCB to ensure that the pins are
soldered on straight.

Blue Pill Board

The procedure for the DIN5 and TRS boards is mostly similar:

0. If you have a rev01 board, ensure you cut the right traces on the PCB.
1. DIN5 board only: Close the following JP9 solder bridge by putting a blob of solder across the middle and upper
   pad, assuming that you use a 74HCT245 chip.
2. Solder all resistors and capacitors. (*A good procedure for this is to put some solder on
   *one* of the two pads, then grab the resistor with the tweezers and push it onto the solder blob
   while still heating the solder blob with your iron. Afterwards, put solder on the other side of
   the part as well.*)
3. Proceed with all ICs. Ensure their correct orientation indicated by a latch on one side, or a
   small dot.
4. If you have a rev01 board, finish the fix by adding the resistors first (similar to the above
   procedure), and then attach the coated wire. Heating your soldering iron to 420C will easily burn
   away the wire coating and ensure good connection. You can now just heat a solder blob and stick
   the wire end into it.
5. Solder the box connectors ("to slave" on the DIN5 board, "from master" on the TRS board), and J3
   on the DIN5 board only. Ensure the correct orientation as denoted on the board.
6. DIN5 board only: Place the 1x20 pin headers on your blue pill board, then insert the header onto
   the PCB and solder it in. Then remove the blue pill board from the headers again.
7. Mount the TRS connectors.
8. Add the LEDs to the TRS board. Stick them
   through the holes so that the short lead is barly sticking out on the soldering side, then bend
   the LEDs over the TRS connectors. Do not rotate the board or they will fall out. When you have
   placed all LEDs, put the TRS case on and ensure all LEDs are held into the right position. Rotate
   the case-board-sandwich and solder the LEDs. Then remove the case again.
   The **long lead** (anode) goes into the **round hole**, and the short lead into the square hole.
9. Solder in the LEDs on the DIN5 board. First, put in the red led and fold it by 90 degrees; then
   put the green led behind and fold it such that it is above the red led.
   Again, the **long lead** (anode) goes into the **round hole**, and the short lead into the square hole.
10. Mount the DIN5 connectors.
11. DIN board only: on the opposite side, solder in the J8 header and the SW1 encoder. You will need
    to trim the two side legs a bit, or they would collide with the ICs on the other side. Soldering
    in the side legs is a bit tricky and must be done "from the wrong side". On the other hand,
    these side legs are optional and only provide stability. Be sure to solder in the rotary knob
    straight, mistakes are impossible to fix.

DIN board
TRS board

Finally, insert the 6-wire 1.27mm pitch lead into the box connector terminators as shown on the
photo. Don't waste wire length. Then push the terminators together with force so they cut
into the wire and form a connection.

Box connectors on cable

Step 3: Testing basic functionality
-----------------------------------

Attach the bare blue pill board via USB to your computer. The power LED should light up and you
should see a Midikraken USB device. Disconnect USB.

Now place the blue pill board on the DIN5 board. Do not attach the display yet. Connect it to USB
again, you should see a Midikraken USB device again. Send some notes to one of the first four ports.
You should see the corresponding LED flashing. Connect a Midikraken's output to one of its inputs.
You should see the input LED flashing, too, when transmitting data. Use MIDI software to check that
you actually receive MIDI data on the input.

Disconnect USB, add the display into the header and re-connect USB. You should see the main menu.
Rotate the button and click to select a menu entry.

Disconnect USB, and connect the TRS board to the DIN5 board using the TRS board's "from master"
connector. Re-attach USB and send MIDI to one of the last eight ports. The TRS board's LEDs should
flash. Connect one of its outputs to one of its inputs, similarly, the input led should flash too
and your MIDI application should register data being received.

Remove all wires.

Step 4a: If you have an enclosure: Enclosure assembly
-----------------------------------------------------

### Shell preparation

First, break of the supports from the DIN enclosure. Then trim away all 3d print artifacts using
a sharp blade:

Breaking the supports
Trimming artifacts

Then snap in the transparent light guides into the TRS and DIN shells. Grab the TRS light guides
with a pair of tweezers, put the TRS case on its side and lay the light guides in place. Then
firmly press them into their holes, starting from the middle. Be sure to not break the walls off.

Inserting the light guides
Snapping in the light guides

Use tweezers to remove the 3d print spaghetti from the screw slots in the TRS board. Grab a string
and twist it around until it comes off.

screw slots
Removing the spaghetti

Finished TRS shell
Finished DIN shell

Mount the display into the display shell from below using the M2 screws and nuts.
Ensure you can slide the four M3 screws through the holes in the display shell. It might be
neccessary to insert them from the opposite side first and to clear any excess plastic / print
artifacts.

Display shell back side
Display shell front side

### Adding the boards

Slide the DIN5 case over the DIN5 connectors. Be sure to not cover the USB connector and that
the nose in the middle latches into the middle two DIN5 connectors for improved stability.

Latching in the DIN shell

Plug in the master/slave cable into the TRS board's *"from master"* header and place the four M3 nuts into the slots in the
enclosure. Make sure they don't fall out. Put the TRS board on top. Once the board is in place, the
nuts are held in place and cannot fall out any more. Screw in the 22mm M3 brass spacers to lock
everything in place. Be sure that the master/slave cable comes out at the small slot in the PCB.

Cable inserted into the TRS board
Finished TRS assembly

*Note: the photos show the wrong orientation. The cable must be inserted into "from master", not into
"to slave" as shown on the photos.*

Now plug in the cable into the "to slave" connector of the DIN5 board. Then place the TRS board on
top / below of the DIN5 board. Screw in the four M3 screws through the display shell and the DIN5
board into the brass spacers.

Inserting the cable into the DIN board
TRS and DIN boards put together

**Carefully** place the display shell on top of the DIN5 board. Ensure that the display pins have
actually met the display socket. Put the button knob on the button to provisorily lock the shell in
place. Attach USB and check whether the display still works. Disconnect USB again.

Congratulations, your Midikraken is complete. :)

Finished Midikraken
Finished Midikraken

Step 4b: If you prefer the half-open solution: Assembly
-------------------------------------------------------

Screw the 4x TODO mm spacers into the spare PCB / bottom plate and secure them with the M3 nuts.

Mount the TRS board on top using the 16mm spacers.

Connect the TRS board and the DIN5 board using the master/slave connections, put the DIN5 board on
top of the TRS board and screw in the 22mm spacers.

Mount the display into the display plate using the M2 screws and nuts.

**Carefully** place the display place on top of the 22mm spacers. Ensure that the display pins have
actually met the display socket. Screw everything together using the M3 screws.

Congratulations, your Midikraken is complete. :)

Troubleshooting
---------------

**All output leds on the TRS board are lit.** Is the cable should be plugged into the TRS board's "from
master" socket, as it should be?

**No display output.** Have the display pins actually met the display header on the board? Inserting them
right can be a bit tricky.

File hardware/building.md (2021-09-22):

Midikraken build howto
======================

Since Midikraken is designed to be modular and is quite configurable, countless configuration
options exist. Not all of them can be described here, and not all of them have been actually tried.

The following guide will focus on the following configuration:
- One DIN5-board with a display and the microcontroller.
  (In [A1 B1 C+ D1 E1 configuration](README.md#board-variants))
- One TRS-board. (In [X1 Y1 configuration](README.md#board-variants))

Photo of Midikraken

This guide will leave up to you whether you want an enclosure or whether you prefer the half-open
configuration.

Step 1: Obtaining all parts
---------------------------

Check that you have obtained all parts from
[the din5 BOM](https://htmlpreview.github.io/?https://github.com/Windfisch/midikraken/blob/master/hardware/din5_pcb/bom.html)
and [the TRS BOM](https://htmlpreview.github.io/?https://github.com/Windfisch/midikraken/blob/master/hardware/trs_pcb/bom.html)
(except those in parentheses or those that say "as desired", we'll handle them separately).

Additionally, you require the following parts:

- 1x DIN5 PCB
- 1x TRS PCB
- 2 box connector terminators
- 5cm (or more) of 6x 1.27mm pitch wire for the box connectors.
- **if you want an enclosure**:
  - 3D prints of the three enclosure parts ([din5_shell](cad/din5_shell.FCStd),
    [trs_back_shell](cad/trs_back_shell.FCStd), [display_shell](cad/display_shell.FCStd)). Print
    them in any color your like, black PLA with 0.2mm layer height and 10% cubic infill worked fine
    for me. Rotate the DIN5 shell such that the enforcements are close to the bottom side; use
    paint-on-supports for the mounting latches and for the crossings of the enforcement beams. Use
    no support for the other shells.
  - 3D prints of the light guides: 4x [din5](cad/din5_lightguide.FCStd) and 8x
    [trs](cad/trs_lightguide.FCStd). These *must* be printed in transparent and with 100% infill.
    Overture transparent PETG at 0.1mm layer height worked fine for me.
  - 4x 16mm M3 hex screws
- **else if you prefer the half-open solution**:
  - 3D print of the [display plate](display_plate.FCStd) (or fabricated PCB or any other means of
    manufacturing a plate.
  - One additional DIN5 *or* TRS PCB which is used as bottom plate.
  - Optional: a 3d printed trs_back_shell is useful for aligning the LEDs during build.
  - 4x 6mm M3 screws
  - 4x 16mm brass spacers
  - 4x TODO mm brass spacers
- 4x 22mm brass spacers
- 4x M3 nuts
- 4x 6mm M2 screws
- 4x M2 nuts

Step 2: Soldering the PCBs
--------------------------

First, read [Fixing the DIN5
board](https://github.com/Windfisch/midikraken/blob/master/hardware/README.md#fixing-the-din-board)
and [Fixing the TRS
board](https://github.com/Windfisch/midikraken/blob/master/hardware/README.md#fixing-the-trs-board).

Before soldering anything make the cuts described in these links.

It is expected that you know how to solder DIP and easy SMD components. A quick reminder:

- Use a soldering iron with a flat tip. Pointy tips are bad at transferring heat.
- Heat both the pin and the pad on the PCB well to ensure a good connection.
- Solder "from small to large" parts.

First, put together the blue pill board. You can use a second PCB to ensure that the pins are
soldered on straight.

The procedure for the DIN5 and TRS boards is mostly similar:

0. If you have a rev01 board, ensure you cut the right traces on the PCB.
1. DIN5 board only: Close the following JP9 solder bridge by putting a blob of solder across the middle and upper
   pad, assuming that you use a 74HCT245 chip.
2. Solder all resistors and capacitors. (*A good procedure for this is to put some solder on
   *one* of the two pads, then grab the resistor with the tweezers and push it onto the solder blob
   while still heating the solder blob with your iron. Afterwards, put solder on the other side of
   the part as well.*)
3. Proceed with all ICs. Ensure their correct orientation indicated by a latch on one side, or a
   small dot.
4. If you have a rev01 board, finish the fix by adding the resistors first (similar to the above
   procedure), and then attach the coated wire. Heating your soldering iron to 420C will easily burn
   away the wire coating and ensure good connection. You can now just heat a solder blob and stick
   the wire end into it.
5. Solder the box connectors ("to slave" on the DIN5 board, "from master" on the TRS board), and J3
   on the DIN5 board only. Ensure the correct orientation as denoted on the board.
6. DIN5 board only: Place the 1x20 pin headers on your blue pill board, then insert the header onto
   the PCB and solder it in. Then remove the blue pill board from the headers again.
7. DIN5 board only: Solder in the LEDs. First, put in the red led and fold it by 90 degrees; then
   put the green led behind and fold it such that it is above the red led.
   The **long lead** (anode) goes into the **round hole**, and the short lead into the square hole.
8. Add the connectors.
9. TRS boards only: Add the LEDs. Again, the **long lead** goes into the **round hole**. Stick them
   through the holes so that the short lead is barly sticking out on the soldering side, then bend
   the LEDs over the TRS connectors. Do not rotate the board or they will fall out. When you have
   placed all LEDs, put the TRS case on and ensure all LEDs are held into the right position. Rotate
   the case-board-sandwich and solder the LEDs. Then remove the case again.
10. DIN board only: on the opposite side, solder in the J8 header and the SW1 encoder. You will need
    to trim the two side legs a bit, or they would collide with the ICs on the other side. Soldering
    in the side legs is a bit tricky and must be done "from the wrong side". On the other hand,
    these side legs are optional and only provide stability. Be sure to solder in the rotary knob
    straight, mistakes are impossible to fix.

Finally, insert the 6-wire 1.27mm pitch lead into the box connector terminators as shown on the
photo (TODO). Don't waste wire length. Then push the terminators together with force so they cut
into the wire and form a connection.

Step 3: Testing basic functionality
-----------------------------------

Attach the bare blue pill board via USB to your computer. The power LED should light up and you
should see a Midikraken USB device.

Now place the blue pill board on the DIN5 board. Do not attach the display yet. Connect it to USB
again, you should see a Midikraken USB device again. Send some notes to one of the first four ports.
You should see the corresponding LED flashing. Connect a Midikraken's output to one of its inputs.
You should see the input LED flashing, too, when transmitting data. Use MIDI software to check that
you actually receive MIDI data on the input.

Disconnect USB, add the display into the header and re-connect USB. You should see the main menu.
Rotate the button and click to select a menu entry.

Disconnect USB, and connect the TRS board to the DIN5 board using the TRS board's "from master"
connector. Re-attach USB and send MIDI to one of the last eight ports. The TRS board's LEDs should
flash. Connect one of its outputs to one of its inputs, similarly, the input led should flash too
and your MIDI application should register data being received.

Remove all wires.

Step 4a: If you have an enclosure: Enclosure assembly
-----------------------------------------------------

Mount the display into the display shell from below using the M2 screws and nuts.
Ensure you can slide the four M3 screws through the holes in the display shell. It might be
neccessary to insert them from the opposite side first and to clear any excess plastic / print
artifacts.

**Carefully** place the display shell on top of the DIN5 board. Ensure that the display pins have
actually met the display socket. Put the button knob on the button to provisorily lock the shell in
place. Attach USB and check whether the display still works. Disconnect USB again.

Snap in the four oval light guides into the DIN5 case. (TODO photo)

Then slide the DIN5 case over the DIN5 connectors. Be sure to not cover the USB connector.

Plug in the master/slave cable into the TRS board and place the four M3 nuts into the slots in the
enclosure. Make sure they don't fall out. Now snap in the eight other light guides into the TRS case
and place it on top of the board. Once the board is in place, the nuts are held in place and cannot
fall out any more. Screw in the 22mm M3 brass spacers to lock everything in place. Be sure that the
master/slave cable comes out at the small slot in the PCB.

Now plug in the cable into the "to slave" connector of the DIN5 board. Then place the TRS board on
top / below of the DIN5 board. Screw in the four M3 screws through the display shell and the DIN5
board into the brass spacers.

Congratulations, your Midikraken is complete. :)

Step 4b: If you prefer the half-open solution: Assembly
-------------------------------------------------------

Screw the 4x TODO mm spacers into the spare PCB / bottom plate and secure them with the M3 nuts.

Mount the TRS board on top using the 16mm spacers.

Connect the TRS board and the DIN5 board using the master/slave connections, put the DIN5 board on
top of the TRS board and screw in the 22mm spacers.

Mount the display into the display plate using the M2 screws and nuts.

**Carefully** place the display place on top of the 22mm spacers. Ensure that the display pins have
actually met the display socket. Screw everything together using the M3 screws.

Congratulations, your Midikraken is complete. :)

Troubleshooting
---------------

TODO

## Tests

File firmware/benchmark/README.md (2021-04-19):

# Manual optimization and benchmarking results

Since the `TIM2` timer interrupt has to fire with 3 * 31250 Hz, we have only
768 cpu cycles in between two interrupts at a CPU frequency of 72MHz. This makes
it important to have very efficient code in the software UART processing code.

While one would normally resort to inline assembly, I tried writing this code
in Rust instead and was quite surprised about the very usable results.

The below diagram shows the number of cycles used for different numbers of
software UARTs, and for different code variants.

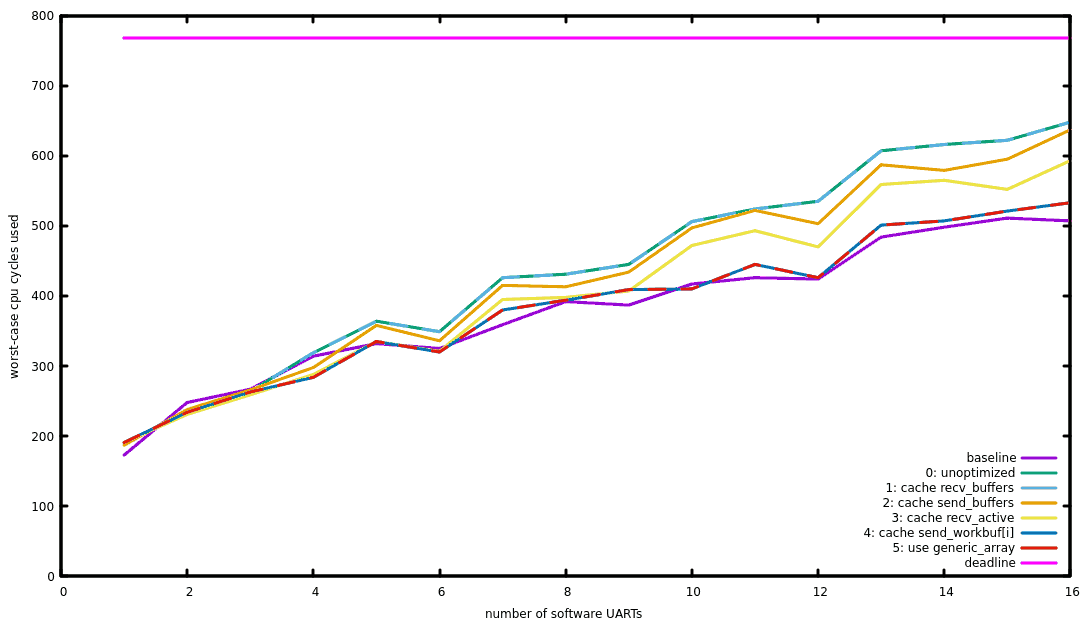
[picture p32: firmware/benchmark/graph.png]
graph


**baseline**: The (mostly unoptimized) software UART was written in Rust and
was tightly integrated with the rest of the program. This yielded the best
results, since any compiler optimizations were easy to see by the compiler.

**0: unoptimized**: By factoring out the software UART into a struct and a
separate file, the compiler could not see some optimizations any more and
generated slower code. While it did inline all code in the `TIM2` handler
as with *baseline*, it created slightly more verbose code and thus failed
to use the `itttt` instruction to avoid conditional branches in some cases.
Also, it did generate unneccessary load and store instructions which could
be avoided by keeping values in the registers.

**1: cache recv_buffers**: Precalculating the array address had no positive effect

```diff
@@ -214,6 +214,7 @@ impl<'a> SoftwareUartIsr<'a> {
                self.recv_active[next_phase] |= start_of_transmission;
 
                let mut recv_finished = 0;
+               let recv_buffers = unsafe { addr_of_mut!((*self.registers).recv_buffers) };
                for i in 0..N_UART {
                        let mask = 1 << i;

@@ -228,7 +229,7 @@ impl<'a> SoftwareUartIsr<'a> {
                                self.recv_workbuf[i] = (self.recv_workbuf[i] >> 1) | recv_bit;
 
                                if self.recv_workbuf[i] & 1 != 0 { // we received 10 bits, i.e. the marker bit is now the LSB?
-                                       unsafe { write_volatile(addr_of_mut!((*self.registers).recv_buffers[i]), self.recv_workbuf[i]); } // publish the received uart frame.
+                                       unsafe { write_volatile(addr_of_mut!((*recv_buffers)[i]), self.recv_workbuf[i]); } // publish the received uart frame.
                                        self.recv_workbuf[i] = RECV_BIT;
                                        recv_finished |= mask;
```

**2: cache send_buffers** considerably improved performance at the sending loop by avoiding accessing the `registers`
pointer in every loop iteration.

```diff
@@ -239,12 +239,13 @@ impl<'a> SoftwareUartIsr<'a> {
 
                // handle the bits to be sent; in three thirdclocks, we prepare *out_bits.
                const SEND_BATCHSIZE: usize = (N_UART+2) / 3;
+               let send_buffers = unsafe { addr_of_mut!((*self.registers).send_buffers) };
                let first = self.phase * SEND_BATCHSIZE;
                for i in first .. core::cmp::min(first + SEND_BATCHSIZE, N_UART) {
                        if self.send_workbuf[i] == 0 {
                                unsafe { // STM32 reads and writes u16s atomically
-                                       self.send_workbuf[i] = read_volatile(addr_of!((*self.registers).send_buffers[i]));
-                                       write_volatile(addr_of_mut!((*self.registers).send_buffers[i]), UART_SEND_IDLE);
+                                       self.send_workbuf[i] = read_volatile(addr_of!((*send_buffers)[i]));
+                                       write_volatile(addr_of_mut!((*send_buffers)[i]), UART_SEND_IDLE);
                                }
                        }
```

**3: cache recv_active** further improved performance by avoiding repeated reads of `recv_active[phase]`:

```diff
@@ -215,11 +215,11 @@ impl<'a> SoftwareUartIsr<'a> {
 
                let mut recv_finished = 0;
                let recv_buffers = unsafe { addr_of_mut!((*self.registers).recv_buffers) };
+               let recv_active = self.recv_active[self.phase];
                for i in 0..N_UART {
                        let mask = 1 << i;

-                       if self.recv_active[self.phase] & mask != 0 { // this is the thirdclock where uart #i can read stable data?
+                       if recv_active & mask != 0 { // this is the thirdclock where uart #i can read stable data?
                                /*let mut recv_bit = 0;
                                if in_bits & mask != 0 {
                                        recv_bit = RECV_BIT;
```

**4: cache send_workbuf[i]**: By fetching `send_workbuf[i]` into a temporary variable, doing all operations
on that variable and only writing back the value at the end, more read/write cycles could be saved:

```diff
@@ -242,15 +242,16 @@ impl<'a> SoftwareUartIsr<'a> {
                let send_buffers = unsafe { addr_of_mut!((*self.registers).send_buffers) };
                let first = self.phase * SEND_BATCHSIZE;
                for i in first .. core::cmp::min(first + SEND_BATCHSIZE, N_UART) {
-                       if self.send_workbuf[i] == 0 {
+                       let mut workbuf = self.send_workbuf[i];
+                       if workbuf == 0 {
                                unsafe { // STM32 reads and writes u16s atomically
-                                       self.send_workbuf[i] = read_volatile(addr_of!((*send_buffers)[i]));
+                                       workbuf = read_volatile(addr_of!((*send_buffers)[i]));
                                        write_volatile(addr_of_mut!((*send_buffers)[i]), UART_SEND_IDLE);
                                }
                        }
                        
-                       self.out_bits |= (self.send_workbuf[i] & 1) << i;
-                       self.send_workbuf[i] >>= 1;
+                       self.out_bits |= (workbuf & 1) << i;
+                       self.send_workbuf[i] = workbuf >> 1;
                }
 
                self.phase = next_phase;
```

**5: use generic_array**: Using the `generic_array` crate to be able to specify the number of uarts as a template argument
did not change anything, as expected:

```diff
@@ -66,50 +68,54 @@ const APP: () = {
-pub struct SoftwareUart {
-       send_buffers: [u16; N_UART],
-       recv_buffers: [u16; N_UART],
+pub struct SoftwareUart<NumUarts: Unsigned + ArrayLength<u16>> {
+       send_buffers: GenericArray<u16, NumUarts>,
+       recv_buffers: GenericArray<u16, NumUarts>,
 }
...
```

The remaining difference to the baseline (with rather ugly code tightly coupled to
the rest of the program) is only a few dozen cycles. These can be explained by the
additional indirections caused by moving the software UART behind a method and
moving its variables behind a `registers` pointer. This difference seems to be
a rather constant offset (up to noise) from the baseline; both seem to scale
equally well with increasing number of software UARTs.

**In conclusion**, it seems that Rust is very well-suited for writing *very* performance-critical code at a
high language level. Best results require some tweaking of the code, e.g. by manually introducing temporary
variables, and you won't get a way without having to read some of the generated assembly code. But Rust
already allows writing highly optimized code without having to resort to inline-assembly or compiler intrinsics.

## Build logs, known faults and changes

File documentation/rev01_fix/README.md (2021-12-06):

# Fixing the DIN board

During powerup, the MIDI ports send garbage bits. To fix this, follow the
steps below. This will delay the *output enable* signal of the output drivers
long enough that the software can set them in their idle states.

## Procedure

On the front side, cut trace A that connects U2's pin 13 to GND. The cut
is marked in red.

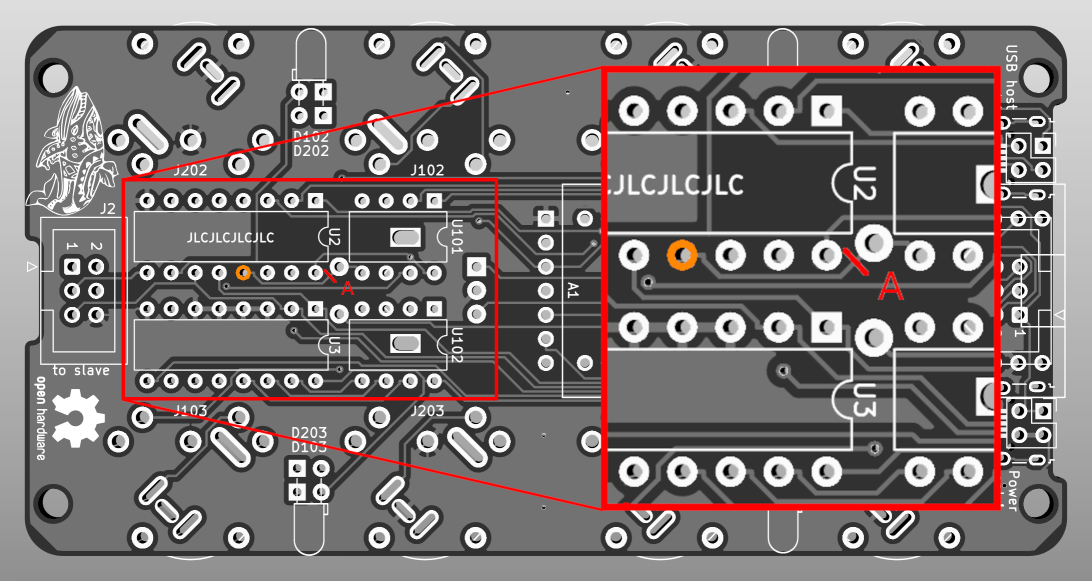
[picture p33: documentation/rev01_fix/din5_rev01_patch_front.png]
Front side


On the back side, cut the two traces at B that connect the same pin to GND.
Then solder a 10k resistor between pins B and C. Solder a 10uF capacitor
to pin D, and connect the other end of the capacitor to pin B using enameled
copper wire.

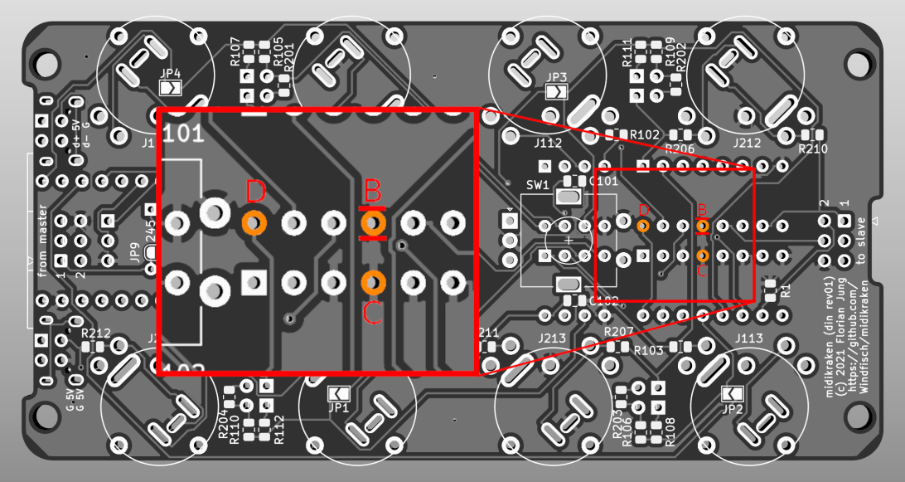
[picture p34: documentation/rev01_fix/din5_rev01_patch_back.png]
Back side


In the end, the fix could look like this:

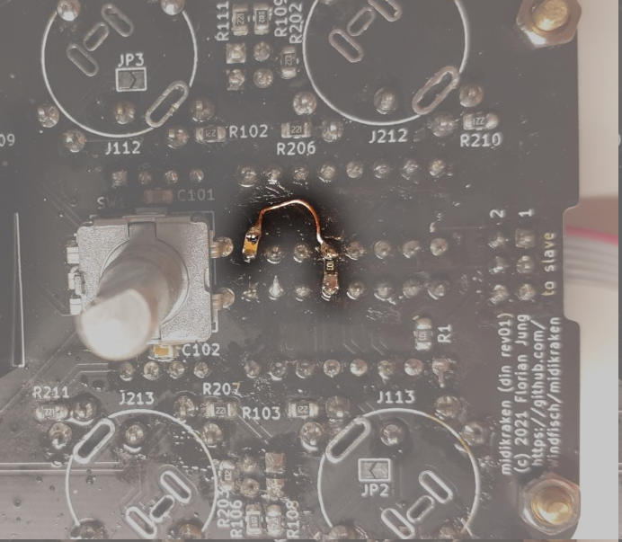
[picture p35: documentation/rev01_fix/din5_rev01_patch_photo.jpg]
Photo of the fixed board


#### Fixing the TRS board

On the front side, cut the two traces marked in red. Then wire a 10uF capacitor from
B to C and a 10k resistor from A to B. It works best to place the resistor on pin A
and the capacitor on pin C, and then run a copper wire from the resistor's other end
across pin B finally to the capacitor's other end.

Doing this once is enough since both ICs' OE
pins are still connected with each other.

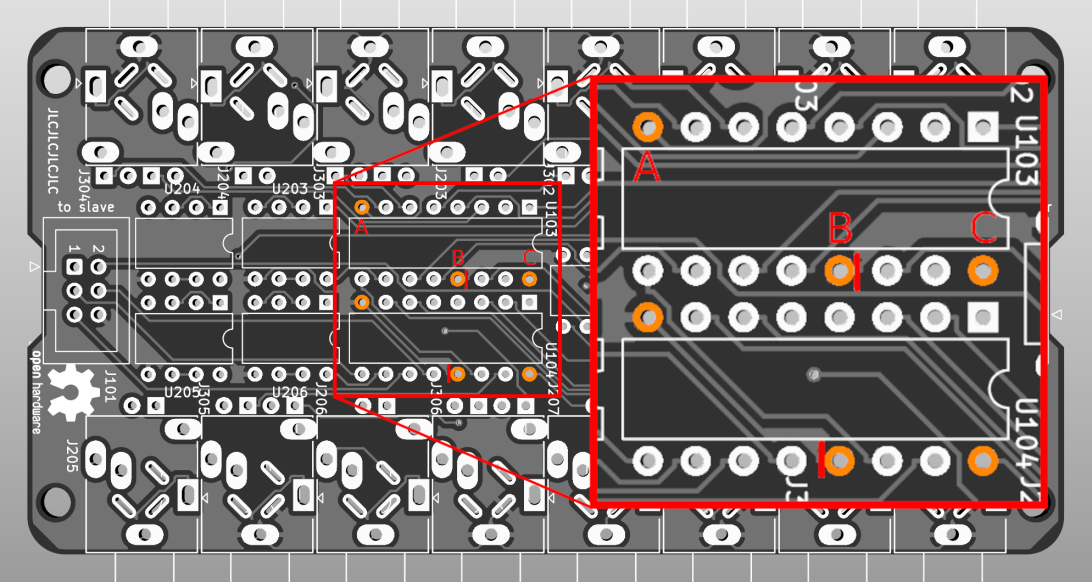
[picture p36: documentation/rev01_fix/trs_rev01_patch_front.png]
Front side


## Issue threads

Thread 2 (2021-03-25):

Revert to interrupt handling instead of main loop polling

Windfisch, 2021-03-25:

Closed 2021-08-09.

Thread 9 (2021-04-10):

Fix detection on Windows

Windfisch, 2021-04-10:
Seems like we have to duplicate every port: one embedded and one external, correctly wired.

Closed 2021-04-12.

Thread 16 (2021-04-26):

layout PCB

Windfisch, 2021-04-26:
note:
- ensure black pill compatibility (one GND must be n/c, RST must be jumperable, one side is pin-shifted by one :/)
- allow for a secondary power plug so the USB can be used as host
- (maybe battery support?)
- stackability (ideally stacking or chaining)
- small display and some buttons
- DIN5 and TRS variants

Closed 2021-06-10.

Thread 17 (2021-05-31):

evaluate Din5 midi pcb options

Windfisch, 2021-05-31:
- [x] Add traces from GPIO pins directly to the inputs/outputs (via the buffer) to enable a shift-register-less build (without the possibility to chain).
- [x] Add solder bridges to skip the buffer and to select 3.3V instead of 5V for 3.3V MIDI operation
- [x] Figure out whether display and rotary encoder can fit on the board.
- [x] HCPL2630 or 6N137?

Closed 2021-06-10.

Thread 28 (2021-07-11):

DIN5 board should skip shift registers

Windfisch, 2021-07-11:
For a master-only-configuration without actual DIN ports, the DIN5 board should allow skipping the shift registers completely.

Currently, this can be achieved by not equipping the shift registers and running wires from 74HC595's SER to QH', and from 74HC165's Q7 to DS.

Solder bridges would be nicer.

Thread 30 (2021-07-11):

Port remapping

Windfisch, 2021-07-11:
Port numbers are weird due to boards being rotated. Fix that in software.

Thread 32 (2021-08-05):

mark correct UART plug orientation on silkscreen

Windfisch, 2021-08-05:

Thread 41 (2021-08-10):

Long-press menu for fancy routing options

Windfisch, 2021-08-10:
- [ ] channel filter
- [ ] channel remap
- [ ] pitch filter
- [ ] velocity manipulator
- [ ] velocity filter
- [ ] transpose

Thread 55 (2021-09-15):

DIN shell needs a support beam and a closed LED cutout

Windfisch, 2021-09-15:

Windfisch, 2021-09-30:
fixed

Closed 2021-09-30.

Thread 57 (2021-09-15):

din shell does not fit

Windfisch, 2021-09-15:
it's a bit too short, because the supported mounting latches are a bit too thick due to the support interface.

Windfisch, 2021-09-30:
fixed

Closed 2021-09-30.

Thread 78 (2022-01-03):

invert encoder direction

Windfisch, 2022-01-03:

Closed 2022-04-03.

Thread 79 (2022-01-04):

trs input schematic has broken part numbers

Windfisch, 2022-01-04:

Windfisch, 2022-01-06:
fixed in cecaaa9991d1444d14fb456283d27df2593f86bc

Closed 2022-01-06.

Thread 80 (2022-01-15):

confusing/missing midi port silkscreen

Windfisch, 2022-01-15:

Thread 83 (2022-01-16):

blue pill silkscreen is missing

Windfisch, 2022-01-16:

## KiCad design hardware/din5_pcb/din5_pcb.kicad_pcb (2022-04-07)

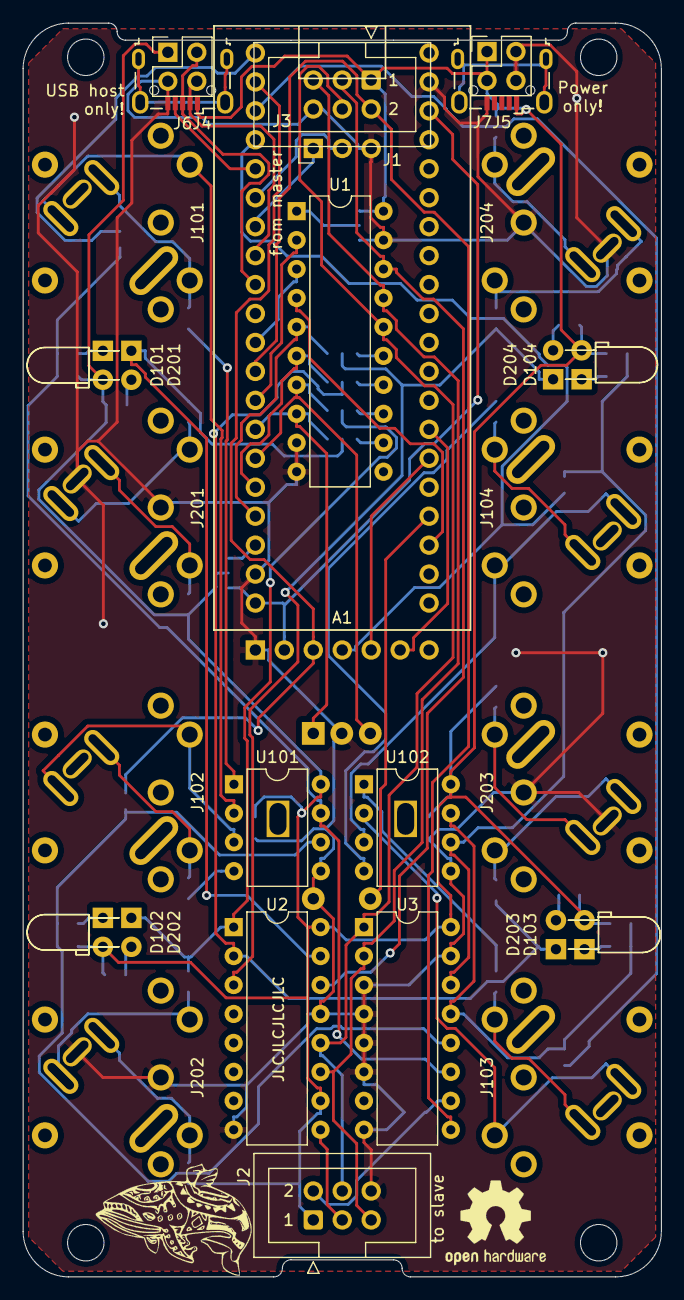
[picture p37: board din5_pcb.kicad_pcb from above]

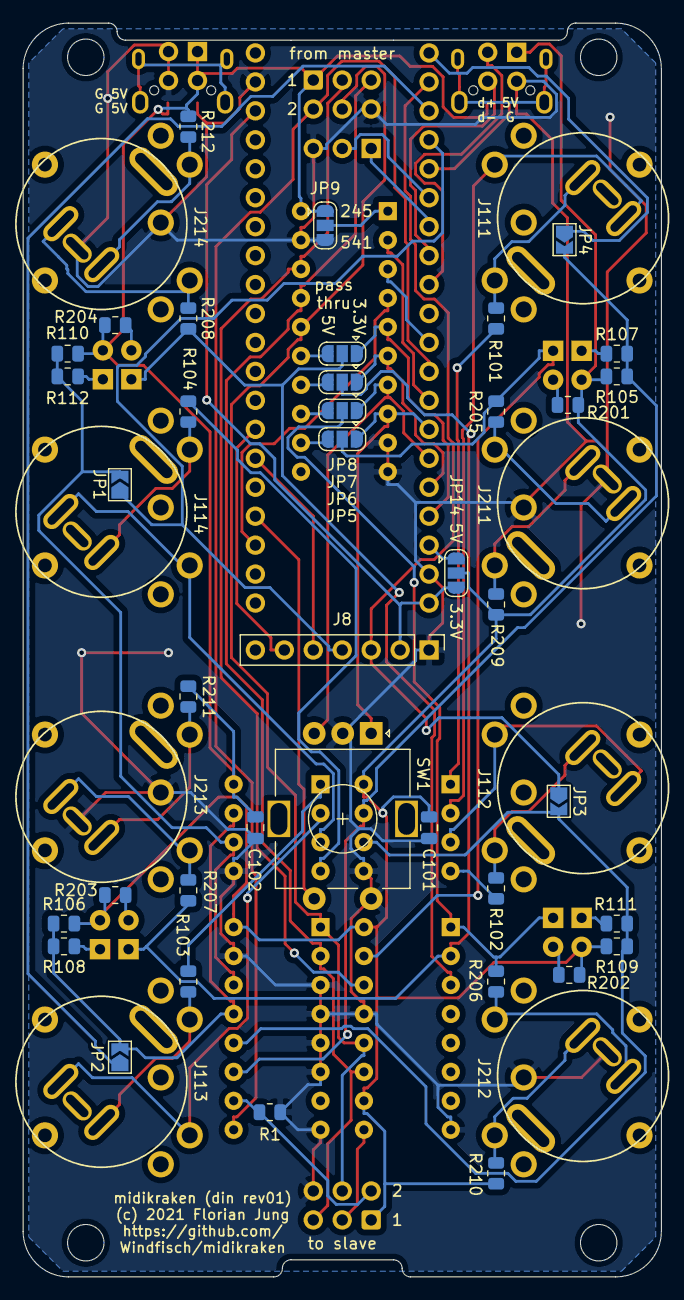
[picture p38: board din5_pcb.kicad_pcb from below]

Board: 2 copper layers, 56.0 x 110.0 mm, 82 parts (47 on the bottom side), 70 nets.

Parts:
A1: BluePill; BLUEPILL-blackpill
C101, C102: 100n; C_0805_2012Metric
D101, D102, D103, D104: LED; LED_D3.0mm_Horizontal_O1.27mm_Z2.0mm
D201, D202, D203, D204: yellow; LED_D3.0mm_Horizontal_O3.81mm_Z6.0mm
J1: Conn_01x03_Male; PinHeader_1x03_P2.54mm_Horizontal
J2, J3: Conn_02x03_Odd_Even; IDC-Header_2x03_P2.54mm_Vertical
J4, J5: USB_B_Micro; USB_Micro-B_Wuerth_629105150521
J6, J7: Conn_02x02_Odd_Even; PinHeader_2x02_P2.54mm_Vertical
J8: Conn_01x07; PinHeader_1x07_P2.54mm_Vertical
J101, J102, J103, J104, J201, J202, J203, J204: DIN-5_180degree; DIN5
J111, J112, J113, J114, J211, J212, J213, J214: do not equip; din5-frickel
JP1, JP2, JP3, JP4: SolderJumper_2_Open; SolderJumper-2_P1.3mm_Open_TrianglePad1.0x1.5mm
JP5, JP6, JP7, JP8: SolderJumper_3_Open; SolderJumper-3_P1.3mm_Open_RoundedPad1.0x1.5mm
JP9, JP14: SolderJumper_3_Bridged12; SolderJumper-3_P1.3mm_Open_RoundedPad1.0x1.5mm
R1: R; R_0805_2012Metric
R101, R102, R103, R104, R107, R108, R111, R112, R205, R206, R207, R208, R209, R210, R211, R212: 220; R_0805_2012Metric
R105, R106, R109, R110, R201, R202, R203, R204: 1k; R_0805_2012Metric
SW1: Rotary_Encoder_Switch; RotaryEncoder_Alps_EC11E-Switch_Vertical_H20mm
U1: 74HCT245; DIP-20_W7.62mm
U2: 74HC595; DIP-16_W7.62mm
U3: 74HC165; DIP-16_W7.62mm
U101, U102: HCPL-2630; DIP-8_W7.62mm
hole1, hole2, hole3, hole4: MountingHole_3.2mm_M3_DIN965
oh: OSHW-Logo2_9.8x8mm_SilkScreen
wf: LOGO; windfisch_smaller

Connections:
+3V3: A1.3V3, J8.2, JP14.3
+5V: A1.5V, JP14.1
GND: A1.G, C101.1, C102.1, J1.3, J2.6, J3.6, J4.5, J5.5, J6.3, J7.2, J7.4, J8.1, J201.2, J202.2, J203.2, J204.2, J211.2, J212.2, J213.2, J214.2, JP9.3, R1.1, SW1.C, SW1.S2, U1.9, U1.10, U1.19, U2.8, U2.13, U3.3, U3.4, U3.5, U3.6, U3.8, U3.15, U101.5, U102.5
MIDI_MISO_CHAIN: J2.2, R1.2, U3.10
MIDI_MOSI_CHAIN: J2.3, U2.9
MISO_MIDI: A1.PB4, J3.2, U3.9
MOSI_MIDI_5: J3.3, U1.18, U2.14
unnamed: A1.PA9, J1.2
unnamed: A1.PA10, J1.1
unnamed: A1.PB3, U1.3
unnamed: A1.PB5, U1.2
unnamed: A1.PB12, JP4.1
unnamed: A1.PB14, JP2.1
unnamed: A1.PC14, U1.4
unnamed: D101.1, R107.1
unnamed: D102.1, R111.1
unnamed: D103.1, R108.1
unnamed: D104.1, R112.1
unnamed: D201.2, R201.2
unnamed: D202.2, R202.2
unnamed: D203.2, R203.2
unnamed: D204.2, R204.2
unnamed: J101.4, J111.4, R101.2
unnamed: J101.5, J111.5, U101.2
unnamed: J102.4, J112.4, R102.2
unnamed: J102.5, J112.5, U101.3
unnamed: J103.4, J113.4, R103.2
unnamed: J103.5, J113.5, U102.2
unnamed: J104.4, J114.4, R104.2
unnamed: J104.5, J114.5, U102.3
unnamed: J201.4, J211.4, R209.1
unnamed: J201.5, J211.5, R205.1
unnamed: J202.4, J212.4, R210.1
unnamed: J202.5, J212.5, R206.1
unnamed: J203.4, J213.4, R211.1
unnamed: J203.5, J213.5, R207.1
unnamed: J204.4, J214.4, R212.1
unnamed: J204.5, J214.5, R208.1
unnamed: JP5.3, U1.12
unnamed: JP6.3, U1.13
unnamed: JP7.3, U1.14
unnamed: JP8.3, U1.15
unnamed: JP9.2, U1.1
unnamed: R101.1, U101.1
unnamed: R102.1, U101.4
unnamed: R103.1, U102.1
unnamed: R104.1, U102.4
PA1: A1.PA1, J8.5
PA2: A1.PA2, J8.6
PB6: A1.PB6, JP5.1, SW1.A, U1.8
PB7: A1.PB7, JP6.1, SW1.B, U1.7
PB8: A1.PB8, JP7.1, U1.6
PB9: A1.PB9, JP8.1, U1.5
PB13: A1.PB13, J8.3, JP3.1
PB15: A1.PB15, J8.4, JP1.1
PC15: A1.PC15, SW1.S1
SCK_MIDI_5: J2.5, J3.5, U1.17, U2.11, U3.2
STROBE_MIDI_5: J2.4, J3.4, U1.16, U2.12, U3.1
USB_DM: A1.PA11, J4.2, J6.4
USB_DP: A1.PA12, J4.3, J6.2
USB_ID: A1.PA8, J4.4
VCC: C101.2, C102.2, D101.2, D102.2, D103.2, D104.2, J2.1, J3.1, J4.1, J5.1, J6.1, J7.1, J7.3, JP9.1, JP14.2, R105.1, R106.1, R109.1, R110.1, R201.1, R202.1, R203.1, R204.1, R209.2, R210.2, R211.2, R212.2, U1.20, U2.10, U2.16, U3.16, U101.8, U102.8
in0: JP4.2, R105.2, R107.2, U3.11, U101.7
in1: JP3.2, R109.2, R111.2, U3.12, U101.6
in2: JP2.2, R106.2, R108.2, U3.13, U102.7
in3: JP1.2, R110.2, R112.2, U3.14, U102.6
out0: D201.1, JP5.2, R205.2, U2.15
out1: D202.1, JP6.2, R206.2, U2.1
out2: D203.1, JP7.2, R207.2, U2.2
out3: D204.1, JP8.2, R208.2, U2.3

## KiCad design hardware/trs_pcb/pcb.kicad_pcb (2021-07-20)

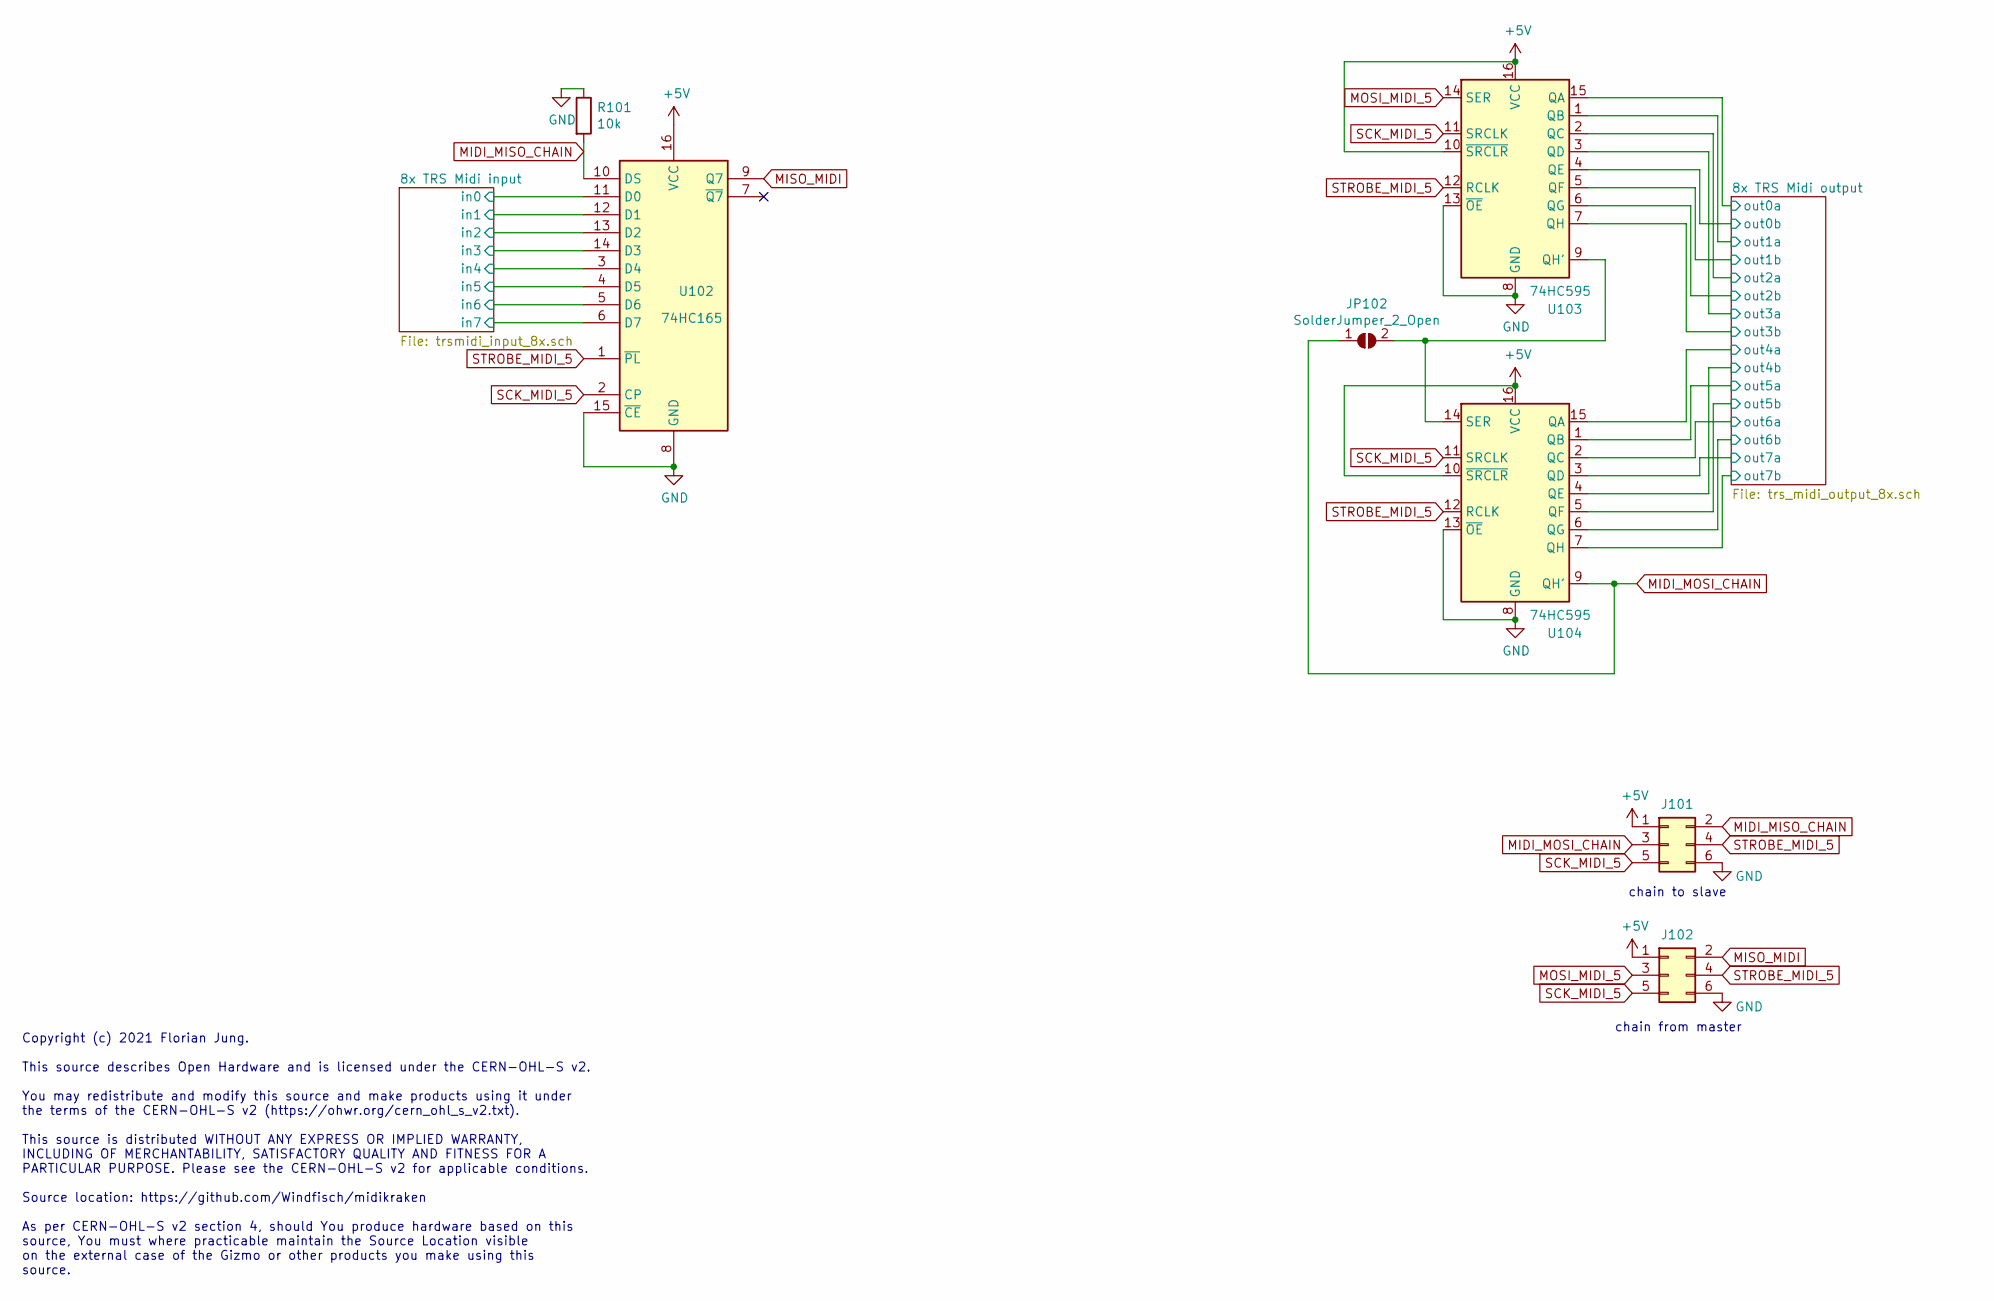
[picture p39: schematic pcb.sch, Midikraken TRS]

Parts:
J101, J102: Conn_02x03_Odd_Even; IDC-Header_2x03_P2.54mm_Vertical
JP102: SolderJumper_2_Open; SolderJumper-2_P1.3mm_Open_TrianglePad1.0x1.5mm
R101: 10k; R_0805_2012Metric
U102: 74HC165; DIP-16_W7.62mm
U103, U104: 74HC595; DIP-16_W7.62mm

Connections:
+5V: J101.1, J102.1, U102.16 (VCC), U103.10 (~SRCLR), U103.16 (VCC), U104.10 (~SRCLR), U104.16 (VCC); also elsewhere on the board
/8x TRS Midi input/in0: U102.11 (D0); also elsewhere on the board
/8x TRS Midi input/in1: U102.12 (D1); also elsewhere on the board
/8x TRS Midi input/in2: U102.13 (D2); also elsewhere on the board
/8x TRS Midi input/in3: U102.14 (D3); also elsewhere on the board
/8x TRS Midi input/in4: U102.3 (D4); also elsewhere on the board
/8x TRS Midi input/in5: U102.4 (D5); also elsewhere on the board
/8x TRS Midi input/in6: U102.5 (D6); also elsewhere on the board
/8x TRS Midi input/in7: U102.6 (D7); also elsewhere on the board
/8x TRS Midi output/out0a: U103.15 (QA); also elsewhere on the board
/8x TRS Midi output/out0b: U103.4 (QE); also elsewhere on the board
/8x TRS Midi output/out1a: U103.1 (QB); also elsewhere on the board
/8x TRS Midi output/out1b: U103.5 (QF); also elsewhere on the board
/8x TRS Midi output/out2a: U103.2 (QC); also elsewhere on the board
/8x TRS Midi output/out2b: U103.6 (QG); also elsewhere on the board
/8x TRS Midi output/out3a: U103.3 (QD); also elsewhere on the board
/8x TRS Midi output/out3b: U103.7 (QH); also elsewhere on the board
/8x TRS Midi output/out4a: U104.15 (QA); also elsewhere on the board
/8x TRS Midi output/out4b: U104.4 (QE); also elsewhere on the board
/8x TRS Midi output/out5a: U104.1 (QB); also elsewhere on the board
/8x TRS Midi output/out5b: U104.5 (QF); also elsewhere on the board
/8x TRS Midi output/out6a: U104.2 (QC); also elsewhere on the board
/8x TRS Midi output/out6b: U104.6 (QG); also elsewhere on the board
/8x TRS Midi output/out7a: U104.3 (QD); also elsewhere on the board
/8x TRS Midi output/out7b: U104.7 (QH); also elsewhere on the board
GND: J101.6, J102.6, R101.1, U102.8 (GND), U102.15 (~CE), U103.8 (GND), U103.13 (~OE), U104.8 (GND), U104.13 (~OE); also elsewhere on the board
MIDI_MISO_CHAIN: J101.2, R101.2, U102.10 (DS)
MIDI_MOSI_CHAIN: J101.3, JP102.1 (A), U104.9 (QH')
MISO_MIDI: J102.2, U102.9 (Q7)
MOSI_MIDI_5: J102.3, U103.14 (SER)
unnamed: JP102.2 (B), U103.9 (QH'), U104.14 (SER)
SCK_MIDI_5: J101.5, J102.5, U102.2 (CP), U103.11 (SRCLK), U104.11 (SRCLK)
STROBE_MIDI_5: J101.4, J102.4, U102.1 (~PL), U103.12 (RCLK), U104.12 (RCLK)

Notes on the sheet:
chain to slave
chain from master
Copyright (c) 2021 Florian Jung. This source describes Open Hardware and is licensed under the CERN-OHL-S v2. You may redistribute and modify this source and make products using it under the terms of the CERN-OHL-S v2 (https://ohwr.org/cern_ohl_s_v2.txt). This source is distributed WITHOUT ANY EXPR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

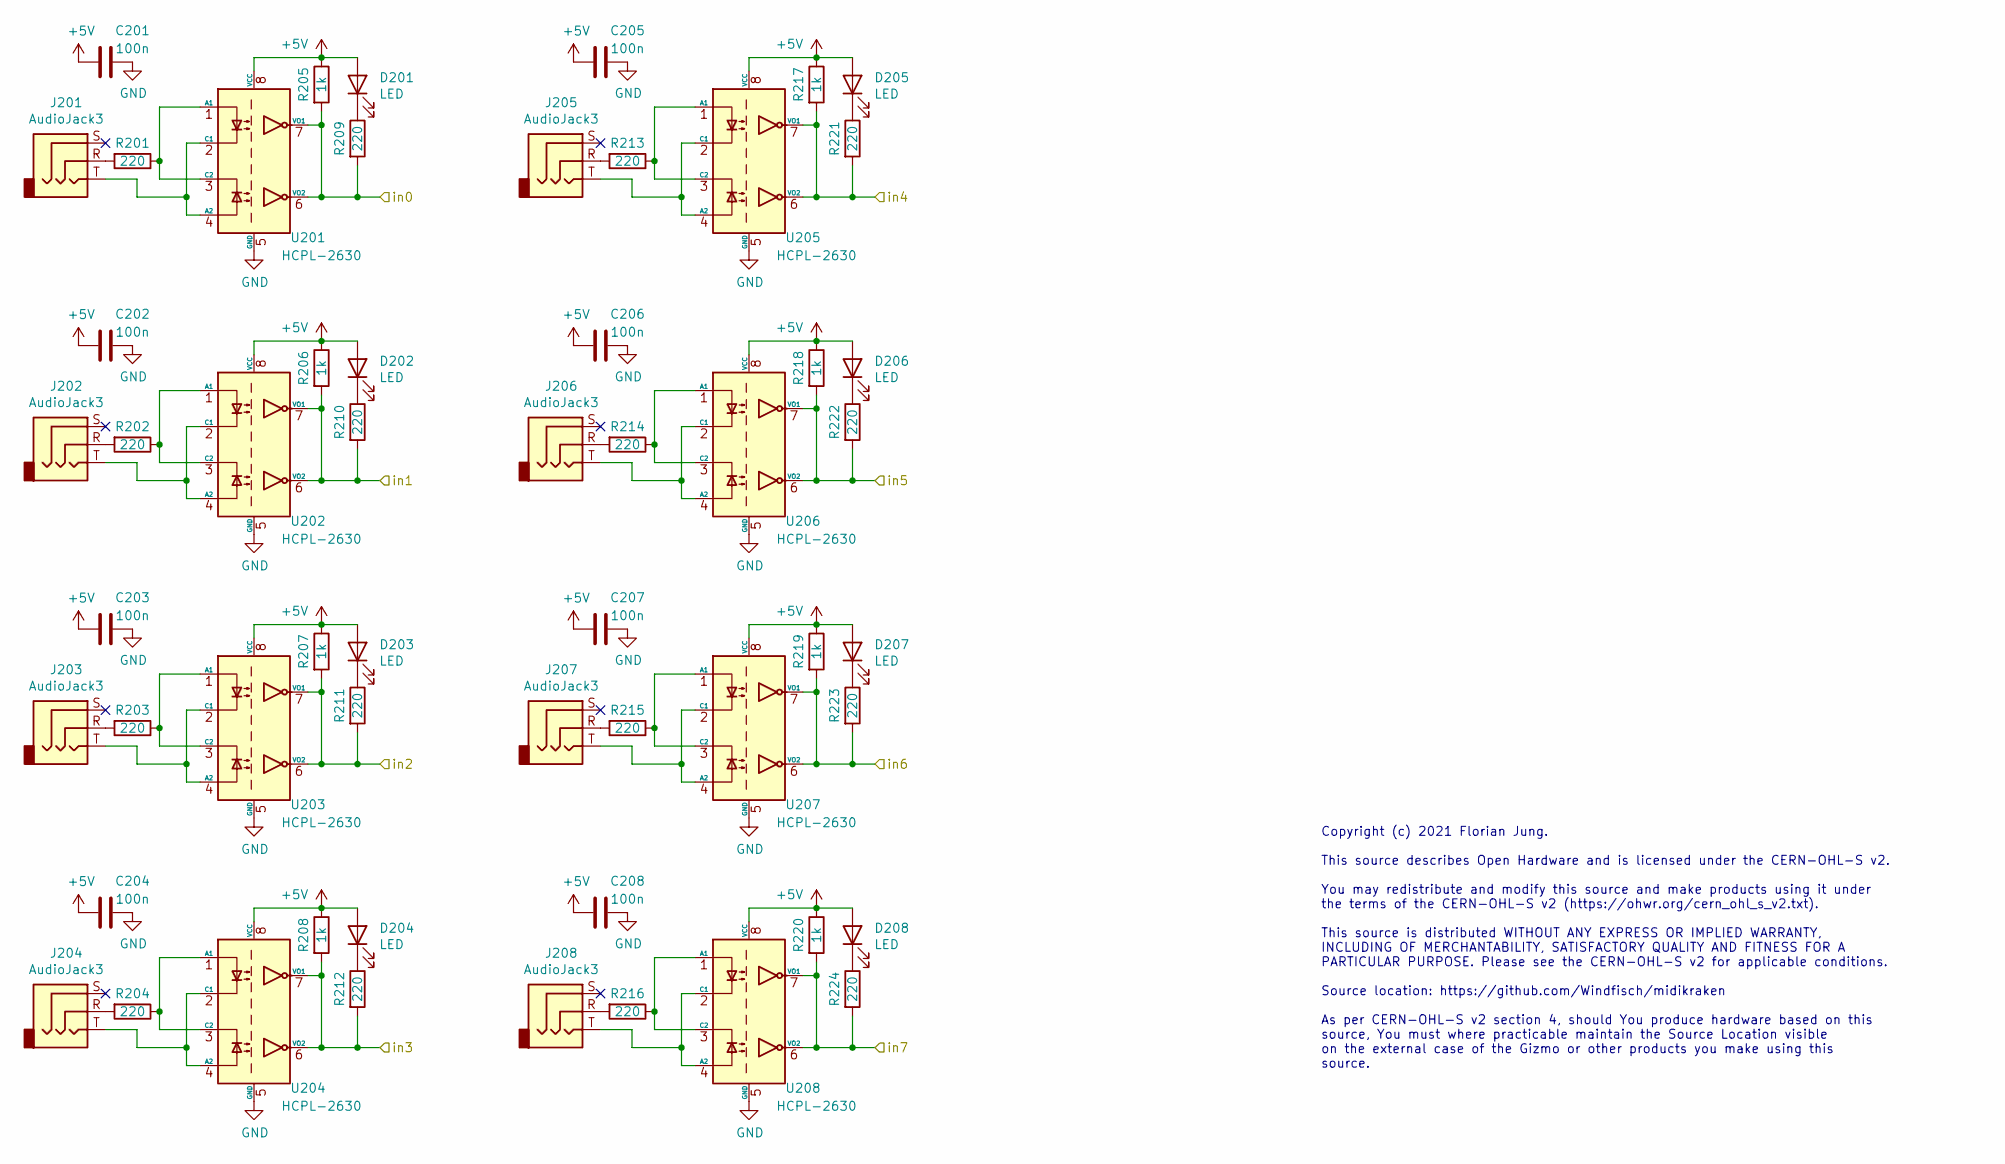
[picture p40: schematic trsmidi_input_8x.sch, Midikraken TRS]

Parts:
C201, C202, C203, C204, C205, C206, C207, C208: 100n; C_0805_2012Metric
D201, D202, D203, D204, D205, D206, D207, D208: LED; LED_D3.0mm_Horizontal_O6.35mm_Z2.0mm
J201, J202, J203, J204, J205, J206, J207, J208: AudioJack3; Jack_3.5mm_combo_ledino_upright
R201, R202, R203, R204, R209, R210, R211, R212, R213, R214, R215, R216, R221, R222, R223, R224: 220; R_0805_2012Metric
R205, R206, R207, R208, R217, R218, R219, R220: 1k; R_0805_2012Metric
U201, U202, U203, U204, U205, U206, U207, U208: HCPL-2630; DIP-8_W7.62mm

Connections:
+5V: C201.2, C202.2, C203.2, C204.2, C205.2, C206.2, C207.2, C208.2, D201.2 (A), D202.2 (A), D203.2 (A), D204.2 (A), D205.2 (A), D206.2 (A), D207.2 (A), D208.2 (A), R205.1, R206.1, R207.1, R208.1, R217.1, R218.1, R219.1, R220.1, U201.8 (VCC), U202.8 (VCC), U203.8 (VCC), U204.8 (VCC), U205.8 (VCC), U206.8 (VCC), U207.8 (VCC), U208.8 (VCC); also elsewhere on the board
/8x TRS Midi input/in0: R205.2, R209.2, U201.6 (VO2), U201.7 (VO1); also elsewhere on the board
/8x TRS Midi input/in1: R206.2, R210.2, U202.6 (VO2), U202.7 (VO1); also elsewhere on the board
/8x TRS Midi input/in2: R207.2, R211.2, U203.6 (VO2), U203.7 (VO1); also elsewhere on the board
/8x TRS Midi input/in3: R208.2, R212.2, U204.6 (VO2), U204.7 (VO1); also elsewhere on the board
/8x TRS Midi input/in4: R217.2, R221.2, U205.6 (VO2), U205.7 (VO1); also elsewhere on the board
/8x TRS Midi input/in5: R218.2, R222.2, U206.6 (VO2), U206.7 (VO1); also elsewhere on the board
/8x TRS Midi input/in6: R219.2, R223.2, U207.6 (VO2), U207.7 (VO1); also elsewhere on the board
/8x TRS Midi input/in7: R220.2, R224.2, U208.6 (VO2), U208.7 (VO1); also elsewhere on the board
GND: C201.1, C202.1, C203.1, C204.1, C205.1, C206.1, C207.1, C208.1, U201.5 (GND), U202.5 (GND), U203.5 (GND), U204.5 (GND), U205.5 (GND), U206.5 (GND), U207.5 (GND), U208.5 (GND); also elsewhere on the board
unnamed: D201.1 (K), R209.1
unnamed: D202.1 (K), R210.1
unnamed: D203.1 (K), R211.1
unnamed: D204.1 (K), R212.1
unnamed: D205.1 (K), R221.1
unnamed: D206.1 (K), R222.1
unnamed: D207.1 (K), R223.1
unnamed: D208.1 (K), R224.1
unnamed: J201.R, R201.2
unnamed: J201.T, U201.2 (C1), U201.4 (A2)
unnamed: J202.R, R202.2
unnamed: J202.T, U202.2 (C1), U202.4 (A2)
unnamed: J203.R, R203.2
unnamed: J203.T, U203.2 (C1), U203.4 (A2)
unnamed: J204.R, R204.2
unnamed: J204.T, U204.2 (C1), U204.4 (A2)
unnamed: J205.R, R213.2
unnamed: J205.T, U205.2 (C1), U205.4 (A2)
unnamed: J206.R, R214.2
unnamed: J206.T, U206.2 (C1), U206.4 (A2)
unnamed: J207.R, R215.2
unnamed: J207.T, U207.2 (C1), U207.4 (A2)
unnamed: J208.R, R216.2
unnamed: J208.T, U208.2 (C1), U208.4 (A2)
unnamed: R201.1, U201.1 (A1), U201.3 (C2)
unnamed: R202.1, U202.1 (A1), U202.3 (C2)
unnamed: R203.1, U203.1 (A1), U203.3 (C2)
unnamed: R204.1, U204.1 (A1), U204.3 (C2)
unnamed: R213.1, U205.1 (A1), U205.3 (C2)
unnamed: R214.1, U206.1 (A1), U206.3 (C2)
unnamed: R215.1, U207.1 (A1), U207.3 (C2)
unnamed: R216.1, U208.1 (A1), U208.3 (C2)

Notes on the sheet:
Copyright (c) 2021 Florian Jung. This source describes Open Hardware and is licensed under the CERN-OHL-S v2. You may redistribute and modify this source and make products using it under the terms of the CERN-OHL-S v2 (https://ohwr.org/cern_ohl_s_v2.txt). This source is distributed WITHOUT ANY EXPR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

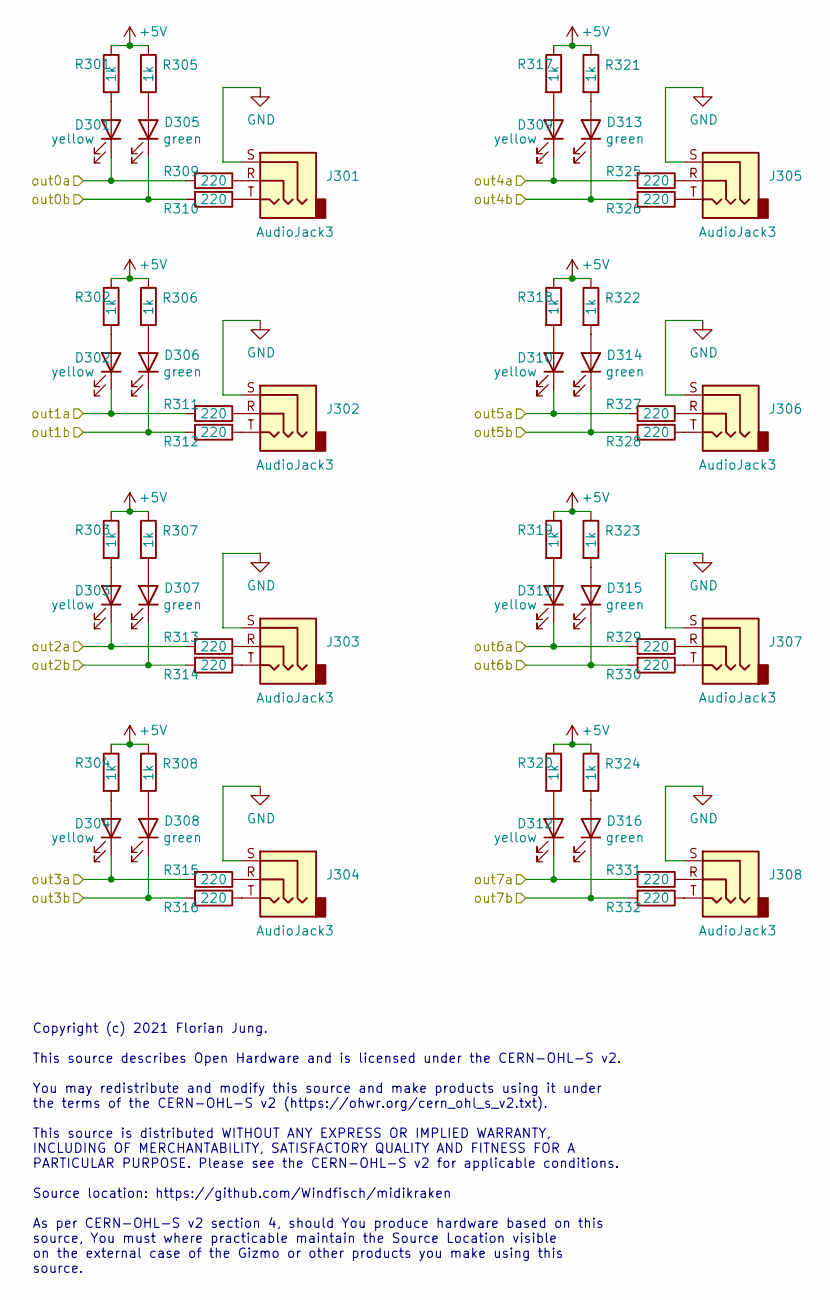
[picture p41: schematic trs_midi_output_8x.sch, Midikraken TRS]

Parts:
D301, D302, D303, D304, D309, D310, D311, D312: yellow; LED_D3.0mm_Horizontal_O6.35mm_Z2.0mm
D305, D306, D307, D308, D313, D314, D315, D316: green; LED_D3.0mm_Horizontal_O6.35mm_Z2.0mm
J301, J302, J303, J304, J305, J306, J307, J308: AudioJack3; Jack_3.5mm_combo_ledino_upright
R301, R302, R303, R304, R305, R306, R307, R308, R317, R318, R319, R320, R321, R322, R323, R324: 1k; R_0805_2012Metric
R309, R310, R311, R312, R313, R314, R315, R316, R325, R326, R327, R328, R329, R330, R331, R332: 220; R_0805_2012Metric

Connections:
+5V: R301.1, R302.1, R303.1, R304.1, R305.1, R306.1, R307.1, R308.1, R317.1, R318.1, R319.1, R320.1, R321.1, R322.1, R323.1, R324.1; also elsewhere on the board
/8x TRS Midi output/out0a: D301.1 (K), R309.2; also elsewhere on the board
/8x TRS Midi output/out0b: D305.1 (K), R310.2; also elsewhere on the board
/8x TRS Midi output/out1a: D302.1 (K), R311.2; also elsewhere on the board
/8x TRS Midi output/out1b: D306.1 (K), R312.2; also elsewhere on the board
/8x TRS Midi output/out2a: D303.1 (K), R313.2; also elsewhere on the board
/8x TRS Midi output/out2b: D307.1 (K), R314.2; also elsewhere on the board
/8x TRS Midi output/out3a: D304.1 (K), R315.2; also elsewhere on the board
/8x TRS Midi output/out3b: D308.1 (K), R316.2; also elsewhere on the board
/8x TRS Midi output/out4a: D309.1 (K), R325.2; also elsewhere on the board
/8x TRS Midi output/out4b: D313.1 (K), R326.2; also elsewhere on the board
/8x TRS Midi output/out5a: D310.1 (K), R327.2; also elsewhere on the board
/8x TRS Midi output/out5b: D314.1 (K), R328.2; also elsewhere on the board
/8x TRS Midi output/out6a: D311.1 (K), R329.2; also elsewhere on the board
/8x TRS Midi output/out6b: D315.1 (K), R330.2; also elsewhere on the board
/8x TRS Midi output/out7a: D312.1 (K), R331.2; also elsewhere on the board
/8x TRS Midi output/out7b: D316.1 (K), R332.2; also elsewhere on the board
GND: J301.S, J302.S, J303.S, J304.S, J305.S, J306.S, J307.S, J308.S; also elsewhere on the board
unnamed: D301.2 (A), R301.2
unnamed: D302.2 (A), R302.2
unnamed: D303.2 (A), R303.2
unnamed: D304.2 (A), R304.2
unnamed: D305.2 (A), R305.2
unnamed: D306.2 (A), R306.2
unnamed: D307.2 (A), R307.2
unnamed: D308.2 (A), R308.2
unnamed: D309.2 (A), R317.2
unnamed: D310.2 (A), R318.2
unnamed: D311.2 (A), R319.2
unnamed: D312.2 (A), R320.2
unnamed: D313.2 (A), R321.2
unnamed: D314.2 (A), R322.2
unnamed: D315.2 (A), R323.2
unnamed: D316.2 (A), R324.2
unnamed: J301.R, R309.1
unnamed: J301.T, R310.1
unnamed: J302.R, R311.1
unnamed: J302.T, R312.1
unnamed: J303.R, R313.1
unnamed: J303.T, R314.1
unnamed: J304.R, R315.1
unnamed: J304.T, R316.1
unnamed: J305.R, R325.1
unnamed: J305.T, R326.1
unnamed: J306.R, R327.1
unnamed: J306.T, R328.1
unnamed: J307.R, R329.1
unnamed: J307.T, R330.1
unnamed: J308.R, R331.1
unnamed: J308.T, R332.1

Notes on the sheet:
Copyright (c) 2021 Florian Jung. This source describes Open Hardware and is licensed under the CERN-OHL-S v2. You may redistribute and modify this source and make products using it under the terms of the CERN-OHL-S v2 (https://ohwr.org/cern_ohl_s_v2.txt). This source is distributed WITHOUT ANY EXPR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

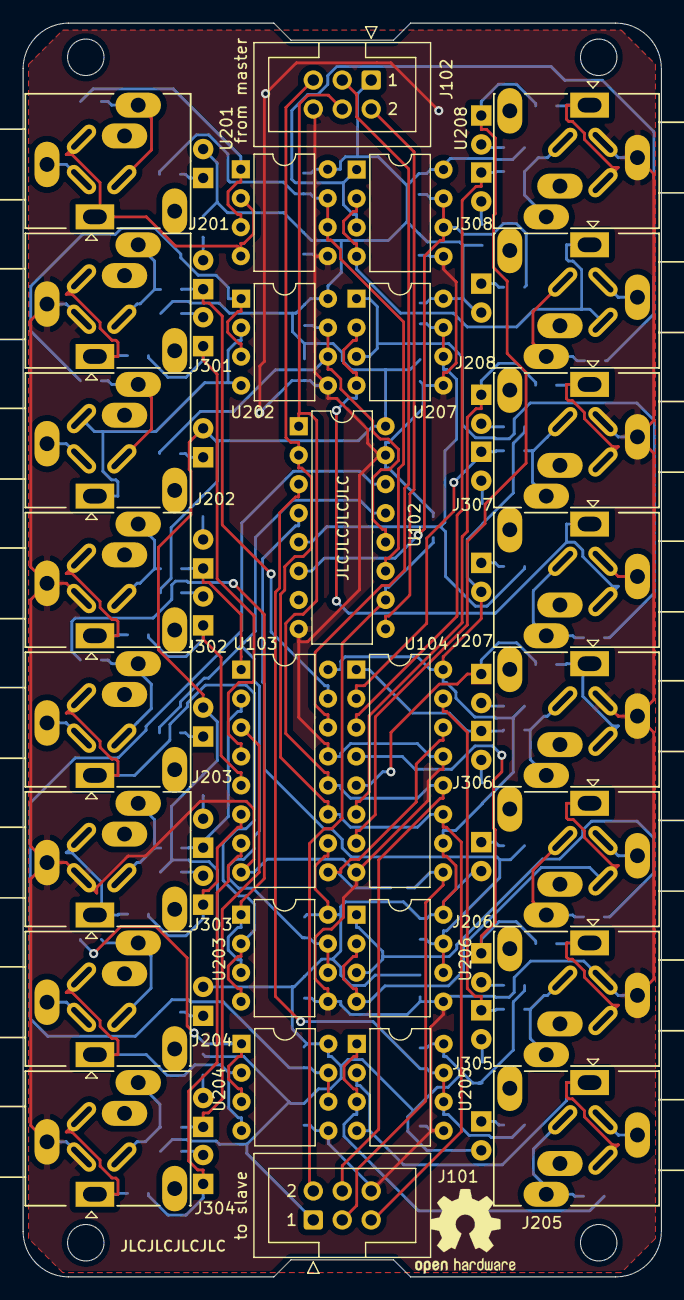
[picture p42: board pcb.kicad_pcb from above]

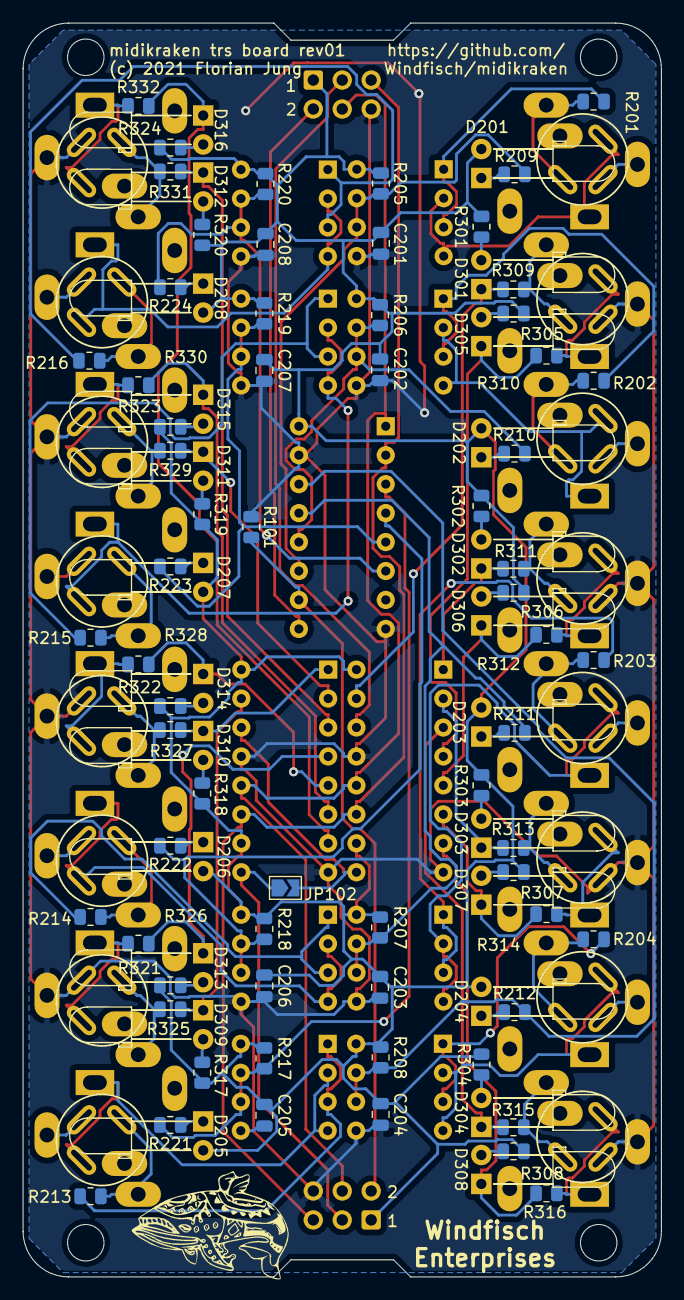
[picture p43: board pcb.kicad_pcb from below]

Board: 2 copper layers, 56.0 x 110.0 mm, 125 parts (91 on the bottom side), 97 nets.

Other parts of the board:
hole1, hole2, hole3, hole4: MountingHole_3.2mm_M3_DIN965
oshw: OSHW-Logo2_9.8x8mm_SilkScreen
wf: LOGO; windfisch_smaller

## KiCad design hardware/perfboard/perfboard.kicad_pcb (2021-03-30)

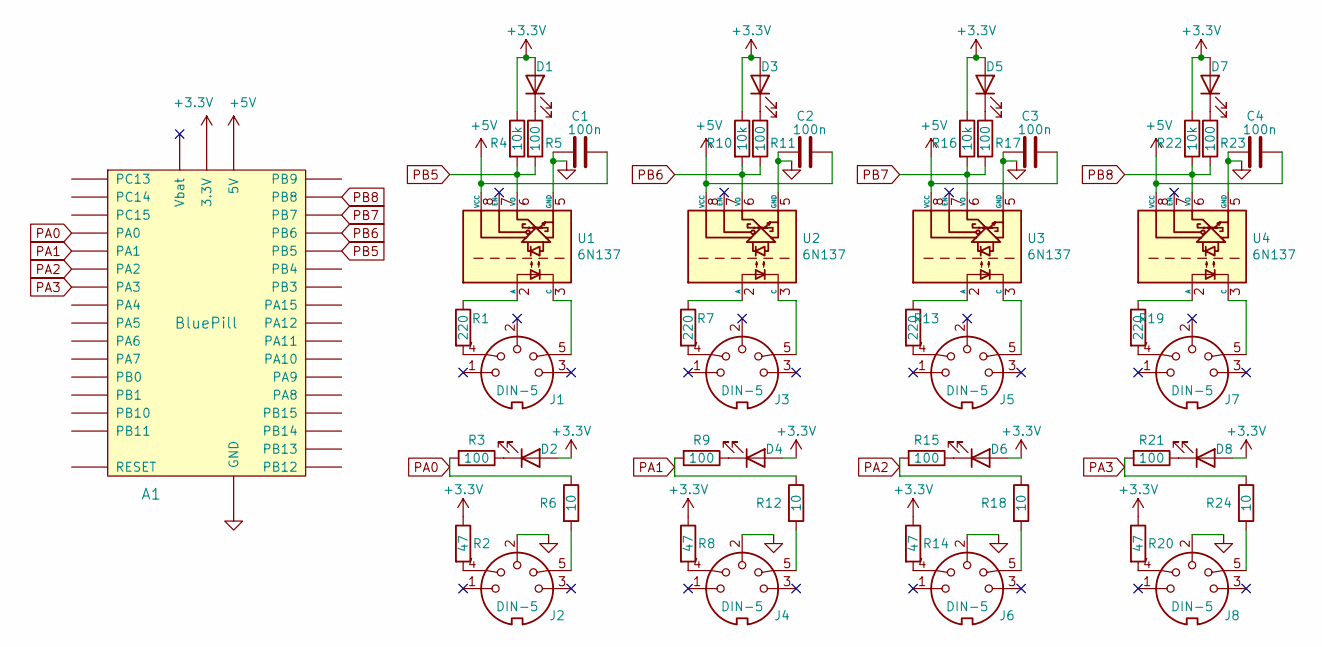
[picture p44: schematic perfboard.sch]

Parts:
A1: BluePill; BLUEPILL
C1, C2, C3, C4: 100n; C_0805_2012Metric
D1, D2, D3, D4, D5, D6, D7, D8: LED; LED_D5.0mm
J1, J2, J3, J4, J5, J6, J7, J8: DIN-5; DIN5
R1, R7, R13, R19: 220; R_0805_2012Metric
R2, R8, R14, R20: 47; R_0805_2012Metric
R3, R5, R9, R11, R15, R17, R21, R23: 100; R_0805_2012Metric
R4, R10, R16, R22: 10k; R_0805_2012Metric
R6, R12, R18, R24: 10; R_0805_2012Metric
U1, U2, U3, U4: 6N137; DIP-8_W7.62mm

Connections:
+3V3: A1.3V3 (3.3V), D1.2 (A), D2.2 (A), D3.2 (A), D4.2 (A), D5.2 (A), D6.2 (A), D7.2 (A), D8.2 (A), R2.1, R4.1, R8.1, R10.1, R14.1, R16.1, R20.1, R22.1
+5V: A1.5V, C1.1, C2.1, C3.1, C4.1, U1.8 (VCC), U2.8 (VCC), U3.8 (VCC), U4.8 (VCC)
GND: A1.G (GND), C1.2, C2.2, C3.2, C4.2, J2.2, J4.2, J6.2, J8.2, U1.5 (GND), U2.5 (GND), U3.5 (GND), U4.5 (GND)
unnamed: D1.1 (K), R5.1
unnamed: D2.1 (K), R3.1
unnamed: D3.1 (K), R11.1
unnamed: D4.1 (K), R9.1
unnamed: D5.1 (K), R17.1
unnamed: D6.1 (K), R15.1
unnamed: D7.1 (K), R23.1
unnamed: D8.1 (K), R21.1
unnamed: J1.4, R1.2
unnamed: J1.5, U1.3 (C)
unnamed: J2.4, R2.2
unnamed: J2.5, R6.2
unnamed: J3.4, R7.2
unnamed: J3.5, U2.3 (C)
unnamed: J4.4, R8.2
unnamed: J4.5, R12.2
unnamed: J5.4, R13.2
unnamed: J5.5, U3.3 (C)
unnamed: J6.4, R14.2
unnamed: J6.5, R18.2
unnamed: J7.4, R19.2
unnamed: J7.5, U4.3 (C)
unnamed: J8.4, R20.2
unnamed: J8.5, R24.2
unnamed: R1.1, U1.2 (A)
unnamed: R7.1, U2.2 (A)
unnamed: R13.1, U3.2 (A)
unnamed: R19.1, U4.2 (A)
PA0: A1.PA0, R3.2, R6.1
PA1: A1.PA1, R9.2, R12.1
PA2: A1.PA2, R15.2, R18.1
PA3: A1.PA3, R21.2, R24.1
PB5: A1.PB5, R4.2, R5.2, U1.6 (VO)
PB6: A1.PB6, R10.2, R11.2, U2.6 (VO)
PB7: A1.PB7, R16.2, R17.2, U3.6 (VO)
PB8: A1.PB8, R22.2, R23.2, U4.6 (VO)

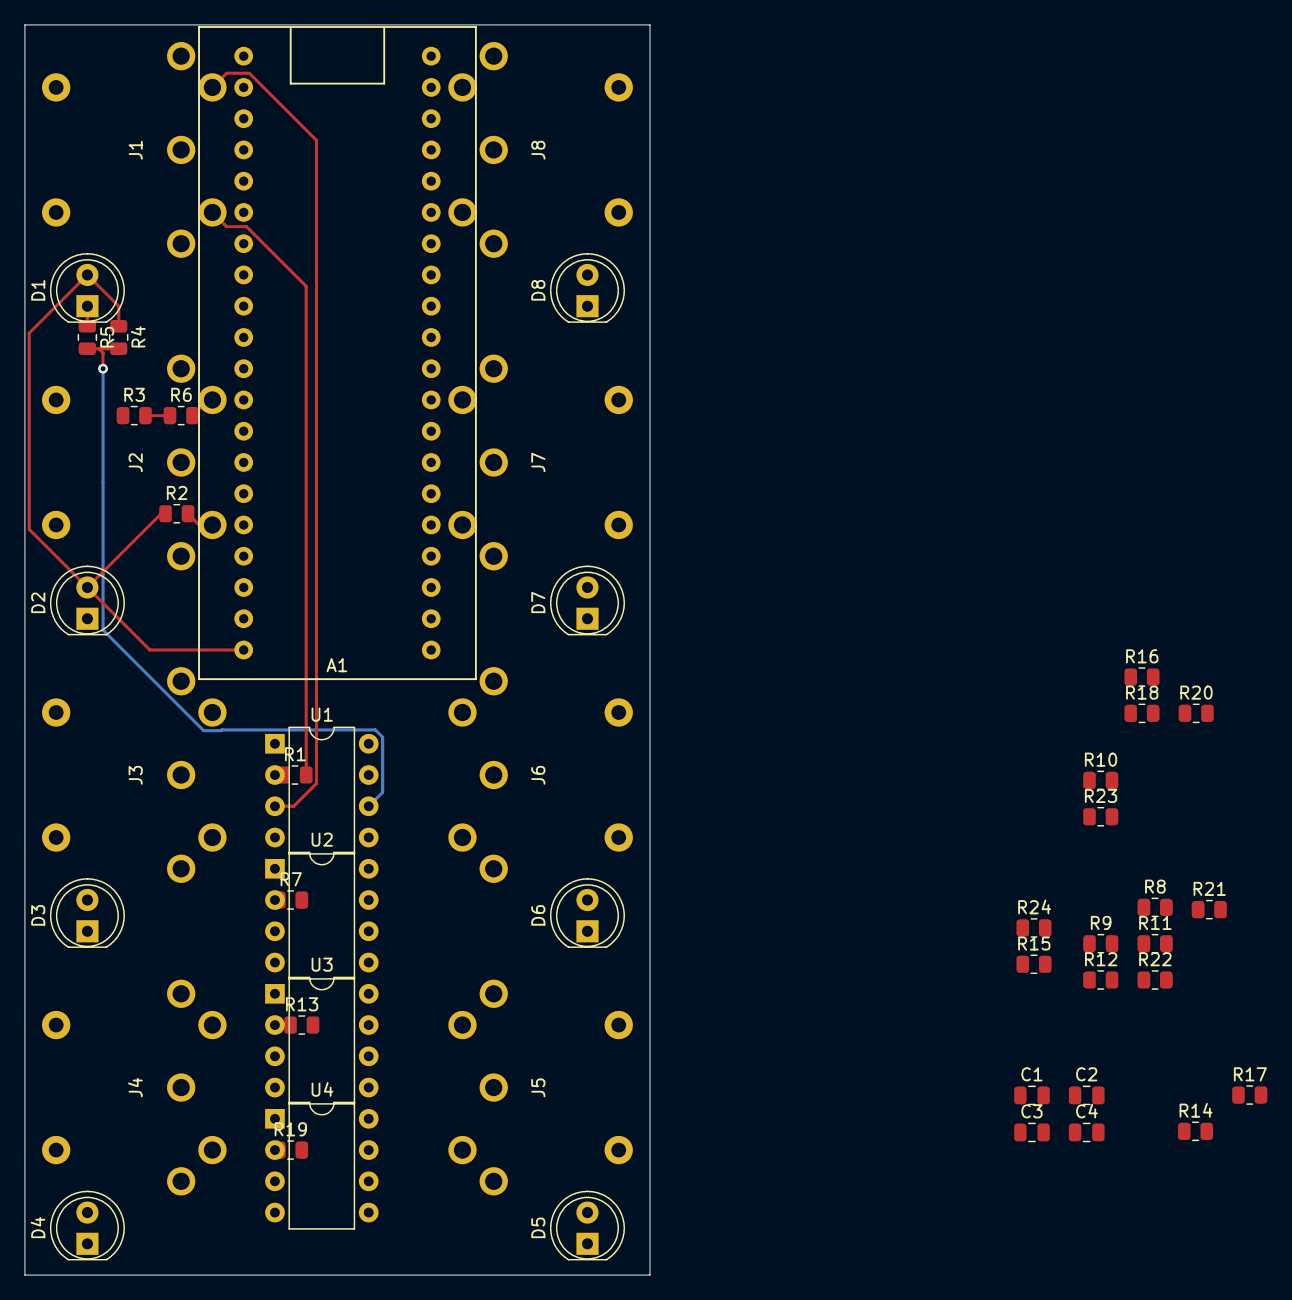
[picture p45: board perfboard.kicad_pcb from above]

Board: 2 copper layers, 50.8 x 101.6 mm, 49 parts (0 on the bottom side), 39 nets.

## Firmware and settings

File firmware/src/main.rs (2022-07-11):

#![no_main]
#![no_std]

/*
Midikraken firmware
Copyright (C) 2021 Florian Jung

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
You should have received a copy of the GNU General Public License
along with this program.  If not, see <http://www.gnu.org/licenses/>.
*/

mod debugln;
mod flash;
mod machine;
mod panic;
mod preset;
mod sysex_bootloader;
#[macro_use]
mod str_writer;
mod display;
mod dma_adapter;
mod gui;
mod gui_task;
mod midi_filter_queue;
mod user_input;

#[allow(unused_imports)]
use debugln::*;

use heapless;
use heapless::spsc::Queue;
use parse_midi;

use flash::MyFlashStore;
use midi_filter_queue::{MidiFilterQueue, MidiFilterQueueConsumer, MidiFilterQueueProducer};
use simple_flash_store::FlashStore;

use sysex_bootloader::BootloaderSysexStatemachine;

#[allow(unused_imports)]
use core::fmt::Write;
use core::sync::atomic::{AtomicBool, AtomicU32, Ordering};
use rtic::app;
use stm32f1xx_hal::time::Hertz;
use stm32f1xx_hal::usb::{Peripheral, UsbBus, UsbBusType};
use stm32f1xx_hal::{
	dma,
	gpio::{gpiob, gpioc, Alternate, Floating, Input, Output, PushPull},
	prelude::*,
	serial, spi, stm32, timer,
};

use dma_adapter::WriteDmaToWriteAdapter;

use usb_device::prelude::*;

use tim2_interrupt_handler::software_uart::*;
use tim2_interrupt_handler::DmaPair;

use preset::*;

const NUM_PORT_PAIRS: usize = 12;

const SYSCLK: Hertz = Hertz(72_000_000);

#[cfg(feature = "benchmark")]
static mut BENCHMARK_CYCLES: u16 = 0;
#[cfg(feature = "benchmark")]
static mut BENCHMARK_PHASE: i8 = -1;

#[cfg(feature = "benchmark")]
fn benchmark(phase: i8) -> u16 {
	if phase < 0 || phase >= 3 {
		return 0;
	}

	unsafe {
		core::ptr::write_volatile(&mut BENCHMARK_CYCLES, 0);
		core::ptr::write_volatile(&mut BENCHMARK_PHASE, phase);
		loop {
			let result = core::ptr::read_volatile(&BENCHMARK_CYCLES);
			if result != 0 {
				return result;
			}
		}
	}
}

pub struct NotifyingQueue<T: Copy, const N: usize> {
	queue: Queue<T, N>,
	notification_pending: bool,
}

impl<T: Copy, const N: usize> NotifyingQueue<T, N> {
	pub fn new() -> NotifyingQueue<T, N> {
		NotifyingQueue {
			queue: Queue::new(),
			notification_pending: false,
		}
	}

	pub fn enqueue(&mut self, value: T) -> Result<(), T> {
		self.queue.enqueue(value)
	}

	pub fn enqueue_all<'a>(&mut self, message: &'a [T]) -> Result<(), &'a [T]> {
		if self.queue.len() + message.len() <= self.queue.capacity() {
			for item in message.iter() {
				self.queue.enqueue(*item).map_err(|_| ()).unwrap();
			}
			return Ok(());
		}
		else {
			return Err(message);
		}
	}

	pub fn dequeue(&mut self) -> Option<(T, bool)> {
		let item = self.queue.dequeue()?;

		if self.queue.is_empty() && self.notification_pending {
			self.notification_pending = false;
			Some((item, true))
		}
		else {
			Some((item, false))
		}
	}

	pub fn request_notification(&mut self) {
		self.notification_pending = true;
	}
}

pub struct MidiOutQueue {
	realtime: NotifyingQueue<u8, 16>,
	normal: NotifyingQueue<u8, 16>,
}

impl Default for MidiOutQueue {
	fn default() -> MidiOutQueue {
		MidiOutQueue {
			realtime: NotifyingQueue::new(),
			normal: NotifyingQueue::new(),
		}
	}
}

impl MidiOutQueue {
	pub fn dequeue(&mut self) -> Option<(u8, bool)> {
		self.realtime.dequeue().or_else(|| self.normal.dequeue())
	}

	pub fn enqueue_usb_message(&mut self, message: [u8; 4], request_notification: bool) -> bool {
		let is_realtime = message[1] & 0xF8 == 0xF8;

		if is_realtime {
			let ok = self.realtime.enqueue(message[1]).is_ok();
			if !ok && request_notification {
				self.realtime.request_notification();
			}
			ok
		}
		else {
			let ok = self.normal.enqueue_all(&message[1..]).is_ok();
			if !ok && request_notification {
				self.normal.request_notification();
			}
			ok
		}
	}
}

static mut DMA_BUFFER: DmaPair = DmaPair::zero();

static OUTPUT_MASK: AtomicU32 = AtomicU32::new(0x000000F0); // FIXME init this to F0F0F0F0

/// Used by the GUI to inhibit all USB-MIDI or MIDI routing activity.
static MIDI_INHIBIT: AtomicBool = AtomicBool::new(false);

#[app(device = stm32f1xx_hal::pac, dispatchers = [EXTI0, EXTI1, EXTI2, EXTI3, EXTI4])]
mod app {

	static mut SOFTWARE_UART: Option<SoftwareUart<NUM_PORT_PAIRS>> = None;
	static mut USB_BUS: Option<usb_device::bus::UsbBusAllocator<UsbBusType>> = None;

	use super::*; // FIXME
	use crate::gui_task::GuiHandler;

	#[shared]
	struct Resources {
		_tx: serial::Tx<stm32::USART1>,
		queue: Queue<(u8, u8), 200>,

		midi: usbd_midi::midi_device::MidiClass<'static, UsbBus<Peripheral>>,

		sw_uart_tx: SoftwareUartTx<'static, NUM_PORT_PAIRS>, // belongs to send_task

		current_preset: Preset,

		midi_out_queues: [MidiOutQueue; 16],
	}

	#[local]
	struct LocalResources {
		clock_count: [u16; 8],
		usb_dev: UsbDevice<'static, UsbBusType>,
		bootloader_sysex_statemachine: BootloaderSysexStatemachine,
		usb_midi_buffer: UsbMidiBuffer,
		mytimer: timer::CountDownTimer<stm32::TIM2>,

		#[cfg(feature = "benchmark")]
		bench_timer: timer::CountDownTimer<stm32::TIM1>,
		midi_parsers: [parse_midi::MidiToUsbParser; 16],

		sw_uart_rx: SoftwareUartRx<'static, NUM_PORT_PAIRS>,
		sw_uart_isr: SoftwareUartIsr<'static, NUM_PORT_PAIRS>,

		spi_strobe_pin: gpioc::PC14<Output<PushPull>>,

		dma_transfer: Option<
			dma::Transfer<
				dma::W,
				(&'static mut [u8; 4], &'static [u8; 4]),
				dma::RxTxDma<
					spi::Spi<
						stm32::SPI1,
						spi::Spi1Remap,
						(
							gpiob::PB3<Alternate<PushPull>>,
							gpiob::PB4<Input<Floating>>,
							gpiob::PB5<Alternate<PushPull>>,
						),
						u8,
					>,
					dma::dma1::C2,
					dma::dma1::C3,
				>,
			>,
		>,

		gui_handler: GuiHandler,
		delay: stm32f1xx_hal::delay::Delay,

		user_input_handler: user_input::UserInputHandler,
		flash_store: MyFlashStore,

		gui_midi_in_producer: MidiFilterQueueProducer<'static, 16>,
		gui_midi_in_consumer: MidiFilterQueueConsumer<'static, 16>,
	}

	#[init(local = [
		gui_midi_in: MidiFilterQueue<16> = MidiFilterQueue::<16>::new(),
	])]
	fn init(cx: init::Context) -> (Resources, LocalResources, init::Monotonics) {
		let dp = cx.device;

		// Clock configuration
		let mut flash = dp.FLASH.constrain();
		let rcc = dp.RCC.constrain();

		let clocks = rcc
			.cfgr
			.use_hse(8.mhz())
			.sysclk(SYSCLK)
			.pclk1(36.mhz())
			.pclk2(72.mhz())
			.freeze(&mut flash.acr);

		assert!(clocks.usbclk_valid());

		let delay = stm32f1xx_hal::delay::Delay::new(cx.core.SYST, clocks);

		// GPIO and peripheral configuration
		let mut afio = dp.AFIO.constrain();
		let mut gpioa = dp.GPIOA.split();
		let mut gpiob = dp.GPIOB.split();
		let mut gpioc = dp.GPIOC.split();
		let (_pa15, pb3, pb4) = afio.mapr.disable_jtag(gpioa.pa15, gpiob.pb3, gpiob.pb4);

		// Configure the on-board LED (PC13, green)
		let mut led = gpioc.pc13.into_push_pull_output(&mut gpioc.crh);
		led.set_high(); // Turn off

		// SPI
		let mut spi_strobe_pin = gpioc
			.pc14
			.into_push_pull_output_with_state(&mut gpioc.crh, stm32f1xx_hal::gpio::PinState::Low); // controls shift registers
		let clk = pb3.into_alternate_push_pull(&mut gpiob.crl);
		let miso = pb4.into_floating_input(&mut gpiob.crl);
		let mosi = gpiob.pb5.into_alternate_push_pull(&mut gpiob.crl);
		let mut spi = spi::Spi::spi1(
			dp.SPI1,
			(clk, miso, mosi),
			&mut afio.mapr,
			spi::Mode {
				phase: spi::Phase::CaptureOnFirstTransition,
				polarity: spi::Polarity::IdleLow,
			},
			10.mhz(),
			clocks,
		);

		// Quickly set the shift registers to their idle state. This needs to happen as quickly as possible.
		spi.transfer(&mut [0xFF, 0xFF, 0xFF, 0xFF, 0xFF, 0xFF, 0xFF, 0xFF])
			.unwrap();
		spi_strobe_pin.set_high();

		// SPI DMA
		let dma = dp.DMA1.split();
		let spi_dma = spi.with_rx_tx_dma(dma.2, dma.3);
		let spi_dma_transfer = spi_dma.read_write(unsafe { &mut DMA_BUFFER.received }, unsafe {
			&DMA_BUFFER.transmit
		});

		// Configure the USART
		let gpio_tx = gpioa.pa9.into_alternate_push_pull(&mut gpioa.crh);
		let gpio_rx = gpioa.pa10;
		let serial = serial::Serial::usart1(
			dp.USART1,
			(gpio_tx, gpio_rx),
			&mut afio.mapr,
			serial::Config::default().baudrate(115200.bps()),
			clocks,
		);

		#[allow(unused_mut)]
		let (mut tx, _rx) = serial.split();

		#[cfg(feature = "debugprint_version")]
		{
			writeln!(
				tx,
				"========================================================"
			)
			.ok();
			writeln!(
				tx,
				"midikraken {} @ {}",
				env!("VERGEN_GIT_SEMVER"),
				env!("VERGEN_GIT_SHA")
			)
			.ok();
			writeln!(tx, "      built on {}", env!("VERGEN_BUILD_TIMESTAMP")).ok();
			if cfg!(feature = "bootloader") {
				writeln!(tx, "      bootloader enabled").ok();
			}
			else {
				writeln!(tx, "      without bootloader").ok();
			}
			writeln!(
				tx,
				"========================================================\n"
			)
			.ok();
		}

		unsafe {
			SOFTWARE_UART = Some(SoftwareUart::new());
		}
		let (sw_uart_tx, sw_uart_rx, sw_uart_isr) =
			unsafe { SOFTWARE_UART.as_mut().unwrap().split() };

		// Configure the display

		let display_reset = gpioa.pa1.into_push_pull_output(&mut gpioa.crl);
		let display_dc = gpioa.pa2.into_push_pull_output(&mut gpioa.crl);
		let display_clk = gpiob.pb13.into_alternate_push_pull(&mut gpiob.crh);
		let display_mosi = gpiob.pb15.into_alternate_push_pull(&mut gpiob.crh);
		let display_spi = spi::Spi::spi2(
			dp.SPI2,
			(display_clk, spi::NoMiso, display_mosi),
			spi::Mode {
				phase: spi::Phase::CaptureOnFirstTransition,
				polarity: spi::Polarity::IdleHigh,
			},
			18.mhz(),
			clocks,
		);

		let display_dma = display_spi.with_tx_dma(dma.5);
		let adapter = WriteDmaToWriteAdapter::new(display_dma);
		let di = display_interface_spi::SPIInterfaceNoCS::new(adapter, display_dc);
		let display = st7789::ST7789::new(di, display_reset, 240, 240);

		// Configure USB
		// BluePill board has a pull-up resistor on the D+ line.
		// Pull the D+ pin down to send a RESET condition to the USB bus.
		let mut usb_dp = gpioa.pa12.into_push_pull_output(&mut gpioa.crh);
		usb_dp.set_low();
		cortex_m::asm::delay(clocks.sysclk().0 / 100);

		let usb_dm = gpioa.pa11;
		let usb_dp = usb_dp.into_floating_input(&mut gpioa.crh);

		let usb_pins = Peripheral {
			usb: dp.USB,
			pin_dm: usb_dm,
			pin_dp: usb_dp,
		};
		unsafe { USB_BUS = Some(UsbBus::new(usb_pins)) };
		let usb_bus = unsafe { USB_BUS.as_ref().unwrap() };

		let midi = usbd_midi::midi_device::MidiClass::new(
			usb_bus,
			NUM_PORT_PAIRS as u8,
			NUM_PORT_PAIRS as u8,
		)
		.unwrap();
		let usb_dev = UsbDeviceBuilder::new(usb_bus, UsbVidPid(0x1209, 0x2E80))
			.manufacturer("Windfisch")
			.product("Midikraken")
			.serial_number("TEST")
			.device_class(usbd_midi::data::usb::constants::USB_CLASS_NONE)
			.build();

		let mut mytimer = timer::Timer::tim2(dp.TIM2, &clocks).start_count_down(Hertz(31250 * 3));
		mytimer.listen(timer::Event::Update);

		let knob_timer = timer::Timer::tim4(dp.TIM4, &clocks).qei(
			(
				gpiob.pb6.into_pull_up_input(&mut gpiob.crl),
				gpiob.pb7.into_pull_up_input(&mut gpiob.crl),
			),
			&mut afio.mapr,
			stm32f1xx_hal::qei::QeiOptions {
				slave_mode: stm32f1xx_hal::qei::SlaveMode::EncoderMode3,
				auto_reload_value: 65535,
			},
		);
		let knob_button = gpioc.pc15.into_pull_up_input(&mut gpioc.crh);

		let queue = Queue::new();

		#[cfg(feature = "benchmark")]
		let bench_timer = timer::Timer::tim1(dp.TIM1, &clocks, &mut rcc.apb2).start_raw(0, 0xFFFF);

		#[cfg(feature = "benchmark")]
		{
			let start_100 = bench_timer.cnt();
			cortex_m::asm::delay(100);
			let stop_100 = bench_timer.cnt();
			let start_40000 = bench_timer.cnt();
			cortex_m::asm::delay(40000);
			let stop_40000 = bench_timer.cnt();
			writeln!(
				tx,
				"delay for 100 cycles took from cpu cycle {} to {}",
				start_100, stop_100
			)
			.ok();
			writeln!(
				tx,
				"delay for 40000 took from cpu cycle {} to {}",
				start_40000, stop_40000
			)
			.ok();
			writeln!(tx, "sleep(1 second)").ok();
			cortex_m::asm::delay(72000000);
			writeln!(tx, "sleep(1 second)").ok();
			cortex_m::asm::delay(72000000);
			writeln!(tx, "done").ok();

			benchmark_task::spawn().unwrap();
			writeln!(tx, "spawned").ok();
		}

		let mut flash_store = FlashStore::new(flash::FlashAdapter::new(flash));
		let current_preset =
			flash::read_preset_from_flash(0, &mut flash_store).unwrap_or(Preset::new());

		let (gui_midi_in_producer, gui_midi_in_consumer) = cx.local.gui_midi_in.split();

		gui_task::spawn().unwrap();

		return (
			Resources {
				_tx: tx,
				queue,
				midi,
				sw_uart_tx,
				midi_out_queues: Default::default(),
				current_preset,
			},
			LocalResources {
				clock_count: [0; 8],
				bootloader_sysex_statemachine: BootloaderSysexStatemachine::new(),
				usb_dev,
				usb_midi_buffer: UsbMidiBuffer::new(),
				mytimer,
				midi_parsers: Default::default(),
				#[cfg(feature = "benchmark")]
				bench_timer,
				dma_transfer: Some(spi_dma_transfer),
				spi_strobe_pin,
				gui_handler: GuiHandler::new(&mut flash_store, display),
				delay,
				user_input_handler: user_input::UserInputHandler::new(knob_timer, knob_button),
				flash_store,
				sw_uart_rx,
				sw_uart_isr,
				gui_midi_in_consumer,
				gui_midi_in_producer,
			},
			init::Monotonics(),
		);
	}

	#[task(shared = [queue], local = [sw_uart_rx], priority = 15)]
	fn byte_received(mut c: byte_received::Context) {
		for i in 0..NUM_PORT_PAIRS {
			if let Some(byte) = c.local.sw_uart_rx.recv_byte(i) {
				c.shared
					.queue
					.lock(|queue| queue.enqueue((i as u8, byte)))
					.ok(); // we can't do anything about this failing
			}
		}
		handle_received_byte::spawn().ok();
	}

	fn route_message_internally(
		usb_message: [u8; 4],
		cable: u8,
		clock_count: &mut [u16],
		midi_out_queues: &mut [MidiOutQueue],
		preset: &Preset,
	) {
		// process for internal routing
		let is_transport = match usb_message[1] {
			0xF1 | 0xF2 | 0xF3 | 0xFA | 0xFC => true,
			_ => false,
		};
		let is_clock = usb_message[1] == 0xF8;
		let is_control_ish = match usb_message[0] & 0x0F {
			0xB | 0xC | 0xE | 0x4 | 0x5 | 0x6 | 0x7 => true,
			_ => false,
		};
		let is_keyboard_ish = match usb_message[0] & 0x0F {
			0x8 | 0x9 | 0xA | 0xD => true,
			_ => false,
		};

		debug_assert!(preset.clock_routing_table.len() == preset.event_routing_table.len());
		debug_assert!(preset.clock_routing_table[0].len() == preset.event_routing_table[0].len());
		let xlen = preset.clock_routing_table.len();
		let ylen = preset.clock_routing_table[0].len();
		debug_assert!(ylen == clock_count.len());

		if (cable as usize) < ylen {
			let cable_in = cable as usize;

			for cable_out in 0..xlen {
				let forward_event = match preset.event_routing_table[cable_out][cable_in] {
					EventRouteMode::Both => is_control_ish || is_keyboard_ish,
					EventRouteMode::Controller => is_control_ish,
					EventRouteMode::Keyboard => is_keyboard_ish,
					EventRouteMode::None => false,
				};

				let forward_clock = match preset.clock_routing_table[cable_out][cable_in] {
					0 => false,
					division => {
						is_transport || (is_clock && clock_count[cable_in] % (division as u16) == 0)
					}
				};

				if forward_event || forward_clock {
					midi_out_queues[cable_out].enqueue_usb_message(usb_message, false);
					send_task::spawn().ok();
				}
			}

			if usb_message[1] == 0xFA {
				// start
				clock_count[cable_in] = 0;
			}
			if usb_message[1] == 0xF8 {
				// clock
				clock_count[cable_in] = (clock_count[cable_in] + 1) % 27720;
				// 27720 is the least common multiple of 1,2,...,12
			}
		}
	}

	#[task(shared = [queue, midi, current_preset, midi_out_queues], local = [midi_parsers, clock_count, gui_midi_in_producer], priority = 7)]
	fn handle_received_byte(c: handle_received_byte::Context) {
		let handle_received_byte::SharedResources {
			mut queue,
			mut midi,
			mut current_preset,
			mut midi_out_queues,
		} = c.shared;
		let handle_received_byte::LocalResources {
			midi_parsers,
			clock_count,
			gui_midi_in_producer,
		} = c.local;

		while let Some((cable, byte)) = queue.lock(|q| q.dequeue()) {
			if let Some(mut usb_message) = midi_parsers[cable as usize].push(byte) {
				usb_message[0] |= cable << 4;

				gui_midi_in_producer.enqueue(usb_message).ok();

				if MIDI_INHIBIT.load(Ordering::Relaxed) {
					continue;
				}

				// send to usb
				#[cfg(feature = "debugprint_verbose")]
				debug!("MIDI{} >>> USB {:02X?}... ", cable, usb_message);
				let _ret = midi.lock(|midi| midi.send_bytes(usb_message));
				#[cfg(feature = "debugprint_verbose")]
				match _ret {
					Ok(size) => {
						debug!("wrote {} bytes to usb\n", size);
					}
					Err(error) => {
						debug!("error writing to usb: {:?}\n", error);
					}
				}

				current_preset.lock(|current_preset| {
					midi_out_queues.lock(|midi_out_queues| {
						route_message_internally(
							usb_message,
							cable,
							clock_count,
							midi_out_queues,
							current_preset,
						)
					})
				});
			}
		}
	}

	#[task(shared = [sw_uart_tx, midi_out_queues], priority = 8)]
	fn send_task(c: send_task::Context) {
		#[allow(unused_mut, unused_variables)]
		let send_task::SharedResources {
			mut sw_uart_tx,
			mut midi_out_queues,
		} = c.shared;

		let mut notify_usb_isr = false;

		sw_uart_tx.lock(|sw_uart_tx| {
			for cable in 0..NUM_PORT_PAIRS {
				if sw_uart_tx.clear_to_send(cable) {
					if let Some((byte, notify)) = midi_out_queues.lock(|q| q[cable].dequeue()) {
						#[cfg(feature = "debugprint_verbose")]
						debug!("USB >>> MIDI{} {:02X?}...\n", cable, byte);
						sw_uart_tx.send_byte(cable, byte);
						notify_usb_isr |= notify;
					}
				}
			}
		});

		if notify_usb_isr {
			rtic::pend(stm32f1xx_hal::stm32::Interrupt::USB_LP_CAN_RX0);
		}
	}

	use crate::gui_task::gui_task;
	extern "Rust" {
		#[task(shared = [current_preset, midi_out_queues], local = [gui_handler, delay, user_input_handler, flash_store, gui_midi_in_consumer], priority = 1)]
		fn gui_task(c: gui_task::Context);
	}

	#[task(binds = USB_LP_CAN_RX0, shared = [midi_out_queues, midi], local = [usb_dev, usb_midi_buffer, bootloader_sysex_statemachine], priority = 8)]
	fn usb_isr(c: usb_isr::Context) {
		let usb_isr::SharedResources {
			mut midi_out_queues,
			mut midi,
		} = c.shared;
		let usb_isr::LocalResources {
			usb_dev,
			usb_midi_buffer,
			bootloader_sysex_statemachine,
		} = c.local;
		midi.lock(|midi| {
			midi_out_queues.lock(|midi_out_queues| {
				usb_poll(
					usb_dev,
					midi,
					midi_out_queues,
					usb_midi_buffer,
					bootloader_sysex_statemachine,
				)
			})
		});

		send_task::spawn().ok();
	}

	#[cfg(feature = "benchmark")]
	#[task(shared = [sw_uart_tx], priority = 1)]
	fn benchmark_task(mut c: benchmark_task::Context) {
		debugln!("Benchmarking...").ok();
		for i in 0..3 {
			debug!("  cycle# {} ->", i).ok();
			for _ in 0..20 {
				debug!(" {}", benchmark(i)).ok();
			}
			debugln!("").ok();
		}
		debugln!("Done!").ok();
	}

	#[task(binds = TIM2, local = [mytimer, bench_timer, sw_uart_isr, dma_transfer, spi_strobe_pin],  priority=16)]
	fn timer_interrupt(c: timer_interrupt::Context) {
		#[cfg(feature = "benchmark")]
		let do_benchmark = c
			.local
			.sw_uart_isr
			.setup_benchmark(unsafe { core::ptr::read_volatile(&BENCHMARK_PHASE) });
		#[cfg(feature = "benchmark")]
		let start_time = c.local.bench_timer.cnt();

		c.local.mytimer.clear_update_interrupt_flag();

		let (recv_finished, sendbuf_consumed) = unsafe {
			tim2_interrupt_handler::optimized_interrupt_handler(
				c.local.sw_uart_isr,
				c.local.spi_strobe_pin,
				c.local.dma_transfer,
				&mut DMA_BUFFER,
				OUTPUT_MASK.load(Ordering::Relaxed),
			)
		};

		if recv_finished != 0 {
			byte_received::spawn().ok();
		}
		if sendbuf_consumed != 0 {
			send_task::spawn().ok();
		}

		#[cfg(feature = "benchmark")]
		{
			let stop_time = c.local.bench_timer.cnt();
			unsafe {
				if do_benchmark {
					core::ptr::write_volatile(&mut BENCHMARK_PHASE, -1);
					core::ptr::write_volatile(
						&mut BENCHMARK_CYCLES,
						stop_time.wrapping_sub(start_time),
					);
				}
			}
		}
	}
}

pub struct UsbMidiBuffer {
	buffer: [u8; 128],
	head: usize,
	tail: usize,
}

impl UsbMidiBuffer {
	pub fn new() -> UsbMidiBuffer {
		UsbMidiBuffer {
			buffer: [0; 128],
			head: 0,
			tail: 0,
		}
	}
	pub fn peek<B: usb_device::bus::UsbBus>(
		&mut self,
		midi: &mut usbd_midi::midi_device::MidiClass<'static, B>,
	) -> Option<[u8; 4]> {
		use core::convert::TryInto;

		if self.head == self.tail {
			if let Ok(len) = midi.read(&mut self.buffer) {
				self.head = 0;
				self.tail = len;
				assert!(self.tail <= 128);
			}
		}
		if self.head != self.tail {
			assert!(self.tail >= self.head + 4);
			return Some(self.buffer[self.head..self.head + 4].try_into().unwrap());
		}
		None
	}
	pub fn acknowledge(&mut self) {
		self.head += 4;
	}
}

fn usb_poll<B: usb_device::bus::UsbBus>(
	// FIXME inline that function in the usb_isr
	usb_dev: &mut UsbDevice<'static, B>,
	midi: &mut usbd_midi::midi_device::MidiClass<'static, B>,
	midi_out_queues: &mut [MidiOutQueue; 16],
	buffer: &mut UsbMidiBuffer,
	bootloader_sysex_statemachine: &mut BootloaderSysexStatemachine,
) {
	usb_dev.poll(&mut [midi]);

	while let Some(message) = buffer.peek(midi) {
		let cable = (message[0] & 0xF0) >> 4;

		if MIDI_INHIBIT.load(Ordering::Relaxed)
			|| midi_out_queues[cable as usize].enqueue_usb_message(message, true)
		{
			buffer.acknowledge();
		}
		else {
			break;
		}

		let is_realtime = message[1] & 0xF8 == 0xF8;
		if !is_realtime && cable == 0 {
			for i in 0..parse_midi::payload_length(message[0]) {
				bootloader_sysex_statemachine.push(message[1 + i as usize]);
			}
		}
	}
}

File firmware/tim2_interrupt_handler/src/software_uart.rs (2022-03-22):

/*
Midikraken firmware
Copyright (C) 2021 Florian Jung

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
You should have received a copy of the GNU General Public License
along with this program.  If not, see <http://www.gnu.org/licenses/>.
*/

use core::ptr::{read_volatile, write_volatile, addr_of_mut, addr_of};
use core::marker::PhantomData;

const RECV_BIT: u16 = 1 << 10; // we need 11 bits for marker (10) + start (9) + 8x data (8-1) + stop (0) (marker is not actually transmitted over the line)
const UART_SEND_IDLE: u16 = 1;

/** The software uart main struct. Holds the 1 byte send and receive buffers.
  *
  * Typically stored in a static variable and then split() into three resources.
  * The SoftwareUartRx and SoftwareUartTx resources are usually owned by a single
  * receiving / sending task, while the SoftwareUartIsr struct must be owned by a
  * timer interrupt handler which executes at 3x the desired baud rate.
  *
  * Usage example with RTIC:
  * ```
#[app(device = stm32f1xx_hal::pac)]
const APP: () = {
	struct Resources {
		mytimer: timer::CountDownTimer<stm32::TIM2>,
		sw_uart_rx: SoftwareUartRx<'static>,
		sw_uart_tx: SoftwareUartTx<'static>,
		sw_uart_backend: SoftwareUartIsr<'static>,
	}

	#[init(spawn=[benchmark_task, mainloop])]
	fn init(cx : init::Context) -> init::LateResources {
		static mut SOFTWARE_UART: Option<SoftwareUart> = None;
		*SOFTWARE_UART = Some(SoftwareUart::new());
		let (sw_uart_tx, sw_uart_rx, sw_uart_backend) = (*SOFTWARE_UART).as_mut().unwrap().split();
		let mut mytimer =
			timer::Timer::tim2(dp.TIM2, &clocks, &mut rcc.apb1)
			.start_count_down(Hertz(31250 * 3));
		mytimer.listen(timer::Event::Update);
		return init::LateResources { mytimer, sw_uart_tx, sw_uart_rx, sw_uart_backend };
	}

	#[task(binds = TIM2, spawn=[byte_received], resources = [mytimer, sw_uart_isr],  priority=100)]
	fn timer_interrupt(c: timer_interrupt::Context) {
		c.resources.mytimer.clear_update_interrupt_flag();

		// actual I/O is done at the very beginning to minimize jitter

		// input
		let gpiob_in = unsafe { (*stm32::GPIOB::ptr()).idr.read().bits() } as u16; // read the IO port
		let in_bits: u16 = (gpiob_in >> 5) & 0x000F;
		
		// output: *out_bits have been set in the last three thirdclocks.
		if let Some(out_bits) = c.resources.sw_uart_isr.out_bits() {
			const MASK_A: u32 = 0x87FF87FF;
			const MASK_C: u32 = 0xC000C000;
			let bits_a = (out_bits & 0x7FF) | ((out_bits & 0x800) << 4);
			let bits_c = (out_bits & 0x3000) << 2;
			let bsrr_a = (bits_a as u32 | ((!bits_a as u32) << 16)) & MASK_A;
			let bsrr_c = (bits_c as u32 | ((!bits_c as u32) << 16)) & MASK_C;

			unsafe { (*stm32::GPIOA::ptr()).bsrr.write(|w| w.bits(bsrr_a)); }; // we ensure to only access pins
			unsafe { (*stm32::GPIOC::ptr()).bsrr.write(|w| w.bits(bsrr_c)); }; // we own (using MASK_A / MASK_C)
		}

		if c.resources.sw_uart_isr.process(in_bits) != 0 {
			c.spawn.byte_received();
		}
	}
	// TODO FIXME: finish the example
  * ```
  */
pub struct SoftwareUart<const NUM_UARTS: usize> {
	send_buffers: [u16; NUM_UARTS],
	recv_buffers: [u16; NUM_UARTS],
}

/** The timer interrupt handler part of the software uart. */
pub struct SoftwareUartIsr<'a, const NUM_UARTS: usize> {
	in_bits_old: u16,
	recv_active: [u16; 3],
	phase: usize,

	recv_workbuf: [u16; NUM_UARTS],
	send_workbuf: [u16; NUM_UARTS],
	out_bits: u16,

	registers: *mut SoftwareUart<NUM_UARTS>,
	_marker: PhantomData<&'a ()>
}

/** The transmit half of the software uart's frontend. */
pub struct SoftwareUartTx<'a, const NUM_UARTS: usize> {
	registers: *mut SoftwareUart<NUM_UARTS>,
	_marker: PhantomData<&'a ()>
}

/** The receive half of the software uart's frontend. */
pub struct SoftwareUartRx<'a, const NUM_UARTS: usize> {
	registers: *mut SoftwareUart<NUM_UARTS>,
	_marker: PhantomData<&'a ()>
}

unsafe impl<'a, const NUM_UARTS: usize> Send for SoftwareUartIsr<'a, NUM_UARTS> {}
unsafe impl<'a, const NUM_UARTS: usize> Send for SoftwareUartRx<'a, NUM_UARTS> {}
unsafe impl<'a, const NUM_UARTS: usize> Send for SoftwareUartTx<'a, NUM_UARTS> {}

impl<const NUM_UARTS: usize> SoftwareUart<NUM_UARTS> {
	pub fn new() -> SoftwareUart<NUM_UARTS> {
		SoftwareUart {
			send_buffers: [UART_SEND_IDLE; NUM_UARTS],
			recv_buffers: [0; NUM_UARTS],
		}
	}

	pub fn split(&mut self) -> (SoftwareUartTx<NUM_UARTS>, SoftwareUartRx<NUM_UARTS>, SoftwareUartIsr<NUM_UARTS>) {
		return (
			SoftwareUartTx { registers: self, _marker: PhantomData },
			SoftwareUartRx { registers: self, _marker: PhantomData },
			SoftwareUartIsr {
				registers: self,
				in_bits_old: 0,
				recv_active: [0; 3],
				phase: 0,
				recv_workbuf: [RECV_BIT; NUM_UARTS],
				send_workbuf: [0; NUM_UARTS],
				out_bits: 0xFFFF,
				_marker: PhantomData
			}
		);
	}
}

impl<'a, const NUM_UARTS: usize> SoftwareUartTx<'a, NUM_UARTS> {
	/** Returns whether the specified UART is ready to accept another byte to be sent via `send_byte()`
		without overwriting the byte scheduled before. */
	pub fn clear_to_send(&self, index: usize) -> bool {
		unsafe {
			return read_volatile(addr_of!((*self.registers).send_buffers[index])) == UART_SEND_IDLE;
		}
	}

	/** Schedules `data` to be sent out via the specified UART as soon as the current transmission
		(if any) has finished. Should only be called if `clear_to_send` reports `true`.
		Note: Only one byte is buffered, so if `send_byte` is called although not `clear_to_send`,
		the previously buffered byte is lost. */
	pub fn send_byte(&mut self, index: usize, data: u8) {
		unsafe {
			write_volatile(addr_of_mut!((*self.registers).send_buffers[index]), ((data as u16) << 1) | (1 << 9));
		}
	}
}

impl<'a, const NUM_UARTS: usize> SoftwareUartRx<'a, NUM_UARTS> {
	/** Retrieves the last byte received on the specified UART, or `None`.
		Note: Only the last received byte is buffered, so if `recv_byte` is not
		called in time, data is lost. */
	pub fn recv_byte(&mut self, index: usize) -> Option<u8> {
		unsafe {
			let data = read_volatile(addr_of!((*self.registers).recv_buffers[index]));
			write_volatile(addr_of_mut!((*self.registers).recv_buffers[index]), 0);

			if data != 0 {
				return Some(((data >> 2) & 0xFF) as u8); // shift out the marker bit and the start bit. then AND out the stop bit
			}
			else {
				return None;
			}
		}
	}
}
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

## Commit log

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2021-03-14 improve jitter and test sending
    [main.rs]
2021-03-21 Print received bytes via ringbuffer
2021-03-21 Create MIDI interface with 4 virtual cables
2021-03-23 Factor out parse_midi, add tests, fix bugs
    [main.rs]
2021-03-25 USB sort-of seems to work; but hangs when sending too much data from the host
    [main.rs]
2021-03-25 Dirty fix for the freezing issue
    [main.rs]
2021-03-28 Fix usb and subrepo
    [main.rs]
2021-03-30 Adapt firmware for perfboard prototype
2021-03-30 Add schematics for perfboard prototype
    [perfboard.kicad_pcb, perfboard.sch]
2021-03-30 First attempts with FreeCAD
    [perfboard.FCStd]
2021-03-30 Finished midi port pockets
    [perfboard.FCStd]
2021-03-30 Lid with holes
    [perfboard.FCStd]
2021-03-30 Add holes for MIDI ports
    [perfboard.FCStd]
2021-03-30 Add hole for USB port
    [perfboard.FCStd]
2021-03-31 Fix things, reduce top thickness
    [perfboard.FCStd]
2021-03-31 Top drill holes
    [perfboard.FCStd]
2021-03-31 Reduce top height
    [perfboard.FCStd]
2021-03-31 Maybe almost finished?
    [perfboard.FCStd]
2021-04-01 Fix cad model
    [perfboard.FCStd]
2021-04-01 Final case CAD file
    [perfboard.FCStd]
2021-04-09 Change panic handler to write to UART1
2021-04-09 Fix lockup when receiving too many usb midi messages
    [main.rs]
2021-04-09 Replace mem::uninitialized with MaybeUninit
    [main.rs]
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2021-04-09 Fix device name
2021-04-12 Fix UARTs not starting in their idle state upon boot
    [main.rs, software_uart.rs]
2021-04-14 Prepare for bootloader, allow sysex to reset to dfu mode
    [main.rs]
2021-04-15 Improve bootloader tooling, fix bugs
    [main.rs]
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2021-05-28 First attempts using SPI instead of GPIO
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2021-05-30 TRS-midi schematic
    [pcb.kicad_pcb, pcb.sch, trs_midi_output_8x.sch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]
2021-05-30 First attempts at a PCB layout...
    [pcb.kicad_pcb, pcb.sch, trs_midi_output_8x.sch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]
2021-05-31 rename trs pcb
    [pcb.kicad_pcb, pcb.sch, trs_midi_output_8x.sch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]
2021-05-31 din5 pcb
    [din5_midi_input_x4.sch, din5_midi_output_x4.sch, din5_pcb.kicad_pcb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]
2021-06-01 din5 pcb ++
    [din5_pcb.kicad_pcb, din5_pcb.sch]
2021-06-03 din5 board layout
    [din5_pcb.kicad_pcb, din5_pcb.sch]
2021-06-05 Add blackpill-compatible bluepill footprint
2021-06-05 Re-order parts on din5_pcb
    [din5_pcb.kicad_pcb, din5_pcb.sch]
2021-06-06 intermediate commit
    [din5_pcb.kicad_pcb, pcb.kicad_pcb]
2021-06-07 Come layout considerations
    [din5_pcb.kicad_pcb, din5_pcb.sch, pcb.kicad_pcb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]
2021-06-07 din5 socket step file
2021-06-07 din 5 pin pcb finished. todo: autoroute
    [din5_pcb.kicad_pcb, din5_pcb.sch]
2021-06-08 Add janky 5-pin DIN upright connector
2021-06-08 Autorouted board, added 3d models
    [din5_pcb.kicad_pcb]
2021-06-08 final commit[tm] for the din 5 pcb
    [din5_pcb.kicad_pcb]
2021-06-08 place components on trs pcb
    [pcb.kicad_pcb, pcb.sch, trs_midi_output_8x.sch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]
2021-06-11 Fix broken horizontal TRS jack footprint
    [pcb.kicad_pcb]
2021-06-11 Fix big in din schematic
    [din5_pcb.sch]
2021-06-11 Increase bluepill hole size and reroute
    [din5_pcb.kicad_pcb]
2021-06-11 reroute one track
    [din5_pcb.kicad_pcb]
2021-06-11 Final schematic fixes
    [din5_pcb.sch, pcb.sch]
2021-06-11 use proper IDC footprints for connectors
    [din5_pcb.sch, pcb.sch]
2021-06-11 move connectors inwards, reroute
    [din5_pcb.kicad_pcb, din5_pcb.sch, pcb.kicad_pcb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]
2021-06-12 Fix silkscreen, final touches
    [din5_pcb.kicad_pcb, din5_pcb.sch, pcb.kicad_pcb]
2021-07-11 Adjust the actual pins used in the schematic
2021-07-17 Set the shift registers to a defined state as quick as possible after startup
    [din5_pcb.sch]
2021-07-17 Rework directory structure and add license information
    [din5_midi_input_x4.sch, din5_midi_output_x4.sch, din5_pcb.kicad_pcb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]
2021-07-19 Fix schematic paths
2021-07-19 Add license hints to all hardware files
    [din5_pcb.kicad_pcb, din5_pcb.sch, pcb.kicad_pcb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]
2021-07-20 Describe workaround for rev01 bug
    [din5_pcb.kicad_pcb, pcb.kicad_pcb]
2021-07-20 Bill of material
    [din5_pcb.sch, pcb.sch, trs_midi_output_8x.sch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]
2021-08-01 Use pid.codes USB VID/PID
2021-08-04 Increase debug UART baud rate
2021-08-08 Add knob support, fix bug from ISR transition
    [main.rs, software_uart.rs]
2021-08-08 Update to latest stm32f1xx-hal from git
2021-08-08 Remove unsafe code, upgrade to more permissive stm32f1xx-hal w.r.t pin configurations
2021-08-10 Switch between event routing and clock routing menus
2021-08-15 Clean up even more
    Fixes #42
    [main.rs]
2021-08-16 Reset to bootloader after panic
    [main.rs]
2021-08-17 Moved out performance-critical software UART code to other crate
    This is a hack to allow heavily optimizing the TIM2 ISR code (and all
    generics instantiated by it), while optimizing the rest of the code for
    size rather than for speed.
2021-09-03 display top enclosure
    [top_display.FCStd]
2021-09-03 DIN5 enclosure module (too thin)
    [din5_cap.FCStd]
2021-09-03 TRS enclosure (untested)
    [trs_cap.FCStd]
2021-09-03 Flat display plate
    [top_display_flat.FCStd]
2021-09-04 Hopefully the final display cap model
    [display_cap_b.3mf, top_display_B.FCStd]
2021-09-05 Made the display shell thinner, fixed sunken screws, tuned display holes
    [top_display_B.FCStd]
2021-09-05 Fix sunk screw shell
    [top_display_B.FCStd]
2021-09-05 Improve operation naming
    [top_display_B.FCStd]
2021-09-07 TRS back shell
    [back_shell.FCStd]
2021-09-08 Parametrized trs cap
    [back_shell.FCStd]
2021-09-08 add led holes
    [back_shell.FCStd]
2021-09-08 finished back shell
    [back_shell.FCStd]
2021-09-08 back shell ++
    [back_shell.FCStd]
2021-09-08 add connector cutout
    [back_shell.FCStd]
2021-09-12 fix back shell bug
    [back_shell.FCStd]
2021-09-14 first din5 shell v2 attempts
    [din5_shell.FCStd]
2021-09-15 din5 case ++
    [din5_shell.FCStd]
2021-09-15 Add USB cutout
    [din5_shell.FCStd]
2021-09-16 clean up enclosure cad files
    [din5_cap.FCStd, display_cap_b.3mf, display_plate.FCStd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]
2021-09-16 Improve wall stability for DIN shell
    [din5_shell.FCStd]
2021-09-16 Reduce din5 shell tolerances:
    - Reduce jack hole thickness from 3mm to 2.5mm
    - Increase middle clamp distance from 54.75mm to 55mm (which is the actual distance.)
    - Made stability beams thinner (3mm -> 2mm)
    [din5_shell.FCStd]
2021-09-16 din shell: shrunk led cutout a bit to make the shape closed on the bottom line
    [din5_shell.FCStd]
2021-09-17 Moved usb cutout down a bit
    [din5_shell.FCStd]
2021-09-19 Change LED resistors from 1k to 220 Ohm.
    Closes #61.
    [din5_pcb.sch, trs_midi_output_8x.sch]
2021-09-19 Lightguides (to be printed in transparent)
    [din5_lightguide.FCStd, trs_lightguide.FCStd]
2021-10-03 Add kicad front and back plate
    [backplate.kicad_pcb, backplate.sch, frontplate.kicad_pcb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]
2021-10-07 Be more robust when reading corrupt (or wrong-version) saved presets
    [main.rs]
2021-10-07 Add video about SMD soldering
2021-10-17 Fix LED colors, add interactive bom
    [din5_pcb.sch]
2021-10-23 Fix half-open assembly instructions
2021-10-23 Fix crash when writing odd data lengths
    [main.rs]
2021-11-21 Display current preset size
2021-11-30 rotate rev01 fix photo to match schematic images
2022-01-04 Automatic kicad schematic and board view export
2022-01-06 Fix broken schematic
    [trsmidi_input_8x.sch]
2022-01-06 Add git revision to generated schematic export
    Implements #75
2022-03-03 firmware: add udev rule for bootloader usb device permissions
2022-03-19 Only locks are missing
    [main.rs]
2022-03-19 Fix compile error with debugprint_verbose
    [main.rs]
2022-03-19 Fix crash at startup. Finish migration to RTIC 1
    [main.rs]
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2022-03-22 Replace generic-array with const generics (finally!)
    Closes #49.
    [lib.rs, main.rs, software_uart.rs]
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2022-04-03 Allow inverting the encoder direction via settings
    Closes #78
    [gui_task.rs]
2022-04-07 Convert din5_pcb.kicad_pcb to KiCAD 6 format
    [din5_pcb.kicad_pcb]
2022-07-11 Fix timing/missing data issue when the queues run full.
    Fixes #93.
    Essentially, when an UART queue becomes full, the USB task stops sending.
    When the queue becomes non-full again, however, it did not start sending again,
    until another USB interrupt was received for an unrelated reason. This caused
    timing issues that break flashing firmwares via sysex, for example.
    [main.rs]
2022-07-11 More efficient "queue available" notification:
    Only notify the sender tasks when
    1. It has previously failed to add data to the queue
    2. The queue now became completely empty
    [gui_task.rs, main.rs]

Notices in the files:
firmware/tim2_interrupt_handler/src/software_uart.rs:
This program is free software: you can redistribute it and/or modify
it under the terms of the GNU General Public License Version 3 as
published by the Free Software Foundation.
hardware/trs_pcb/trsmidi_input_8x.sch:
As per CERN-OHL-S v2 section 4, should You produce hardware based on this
